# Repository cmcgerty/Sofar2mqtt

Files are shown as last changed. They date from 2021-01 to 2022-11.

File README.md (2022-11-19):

# Sofar2mqtt
## A smart home interface for Sofar solar and battery inverters.

Supported models:  

ME3000SP - Full support  
HYD-xx00-ES - Full support

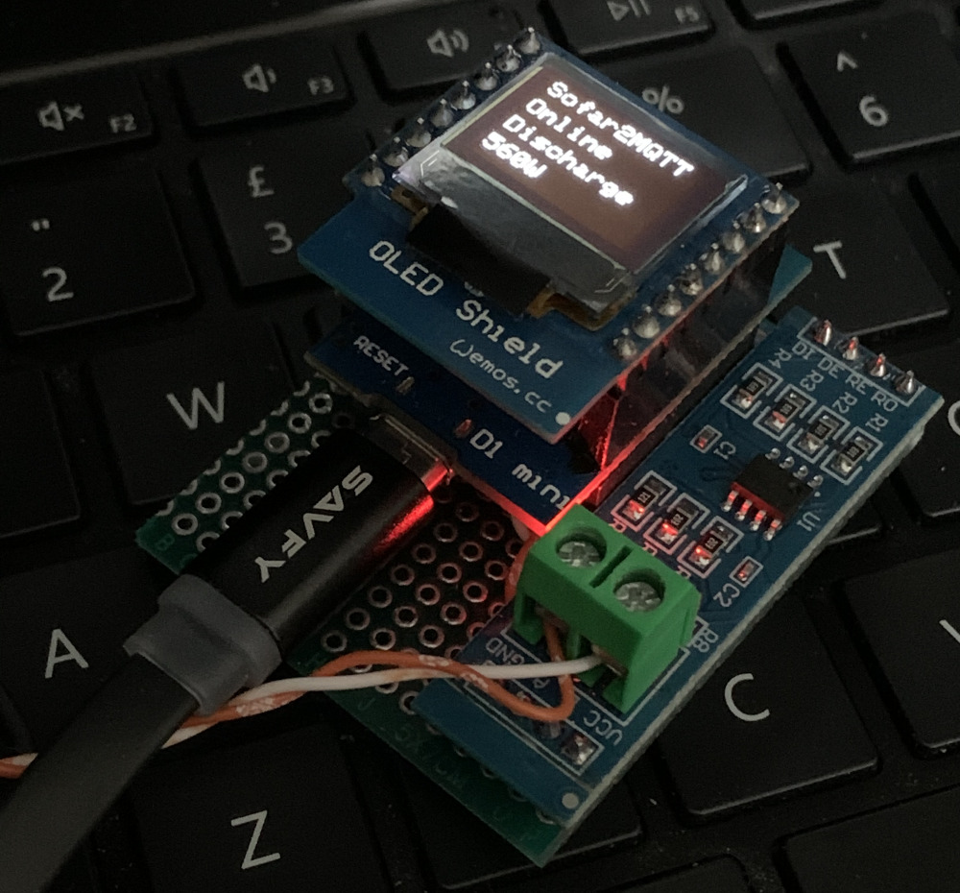
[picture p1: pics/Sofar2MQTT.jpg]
Sofar2MQTT


Sofar2mqtt is a remote control interface for Sofar solar and battery inverters.
It allows remote control of the inverter and reports the invertor status, power usage, battery state etc for integration with smart home systems such as [Home Assistant](https://www.home-assistant.io/) and [Node-Red](https://nodered.org/).  
For read only mode, it will send status messages without the inverter needing to be in passive mode.  
It's designed to run on an ESP8266 microcontroller with a TTL to RS485 module such as MAX485 or MAX3485.  
Designed to work with TTL modules with or without the DR and RE flow control pins. If your TTL module does not have these pins then just ignore the wire from D5. 

Subscribe your MQTT client to:

Sofar2mqtt/state

Which provides:

running_state  
grid_voltage  
grid_current  
grid_freq  
systemIO_power (AC side of inverter)  
battery_power  (DC side of inverter)  
battery_voltage  
battery_current  
batterySOC  
battery_temp  
battery_cycles  
grid_power  
consumption  
solarPV  
today_generation  
today_exported  
today_purchase  
today_consumption  
inverter_temp  
inverterHS_temp  
solarPVAmps  

With the inverter in Passive Mode, send MQTT messages to:

Sofar2mqtt/set/standby   - send value "true"  
Sofar2mqtt/set/auto   - send value "true" or "battery_save"  
Sofar2mqtt/set/charge   - send values in the range 0-3000 (watts)  
Sofar2mqtt/set/discharge   - send values in the range 0-3000 (watts) 

battery_save is a hybrid auto mode that will charge from excess solar but not discharge.

(c)Colin McGerty 2021 colin@mcgerty.co.uk
Major version 2.0 rewrite by Adam Hill sidepipeukatgmaildotcom
Thanks to Rich Platts for hybrid model code and testing.  
calcCRC by angelo.compagnucci@gmail.com and jpmzometa@gmail.com

# How To Build

Parts List:
1. ESP8266 Microcontroller
2. MAX485 or MAX3485 TTL to RS485 board*
3. Wemos 64x48 OLED Screen (optional)
4. A small project board
5. A few wires and a little solder

*The MAX3485 (which is red, not blue like the MAX485 shown here) is preferred as it is much more stable because it uses 3.3v logic, just like the ESP8366. The MAX485 uses 5v logic but is somewhat tolerant of 3.3v and is generally cheaper and more widely available. I use a MAX485 but many people have reported problems with this and if you can find a MAX3485 then you should use that. MAX3485 boards do not have DR and RE flow control pins, so just skip the wire from pin D5 in the wiring diagram below.

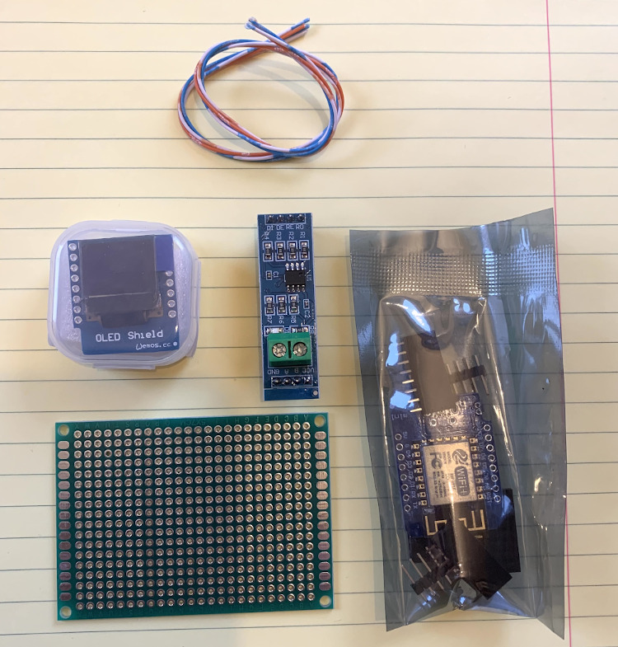
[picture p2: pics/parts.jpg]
Parts


Cut the project board to a convenient size.

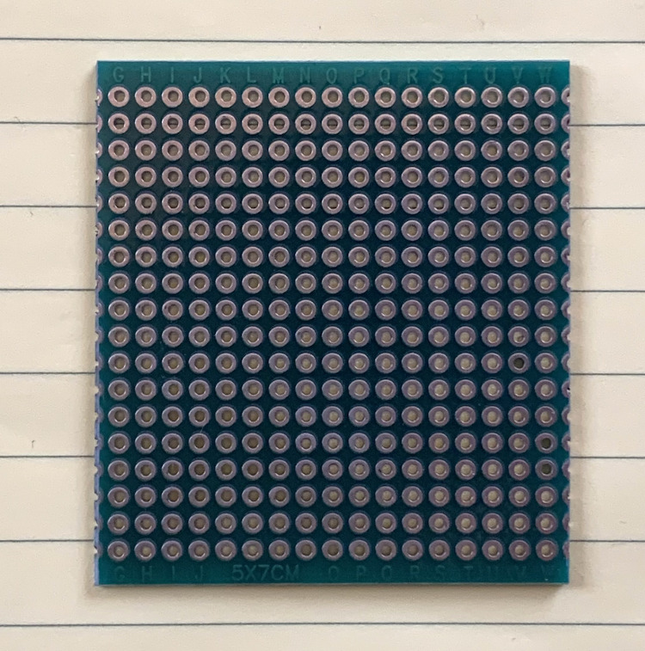
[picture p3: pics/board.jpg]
Board


Wire the components according to this circuit diagram.

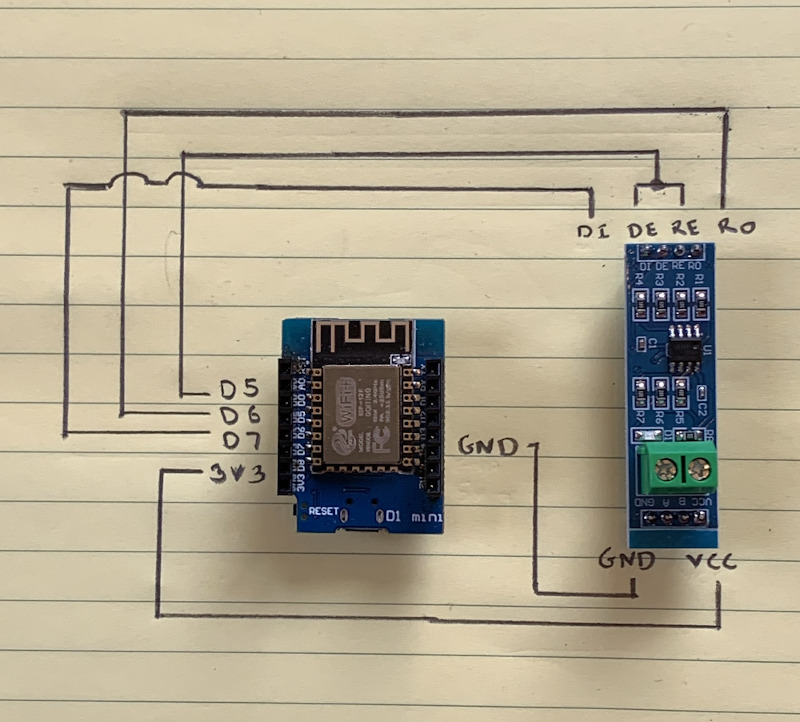
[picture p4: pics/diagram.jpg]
Wiring Diagram


I tend to keep the wires on top of the board, poke them through and solder underneath. Your approach may be better and your soldering will almost certainly be better than mine!

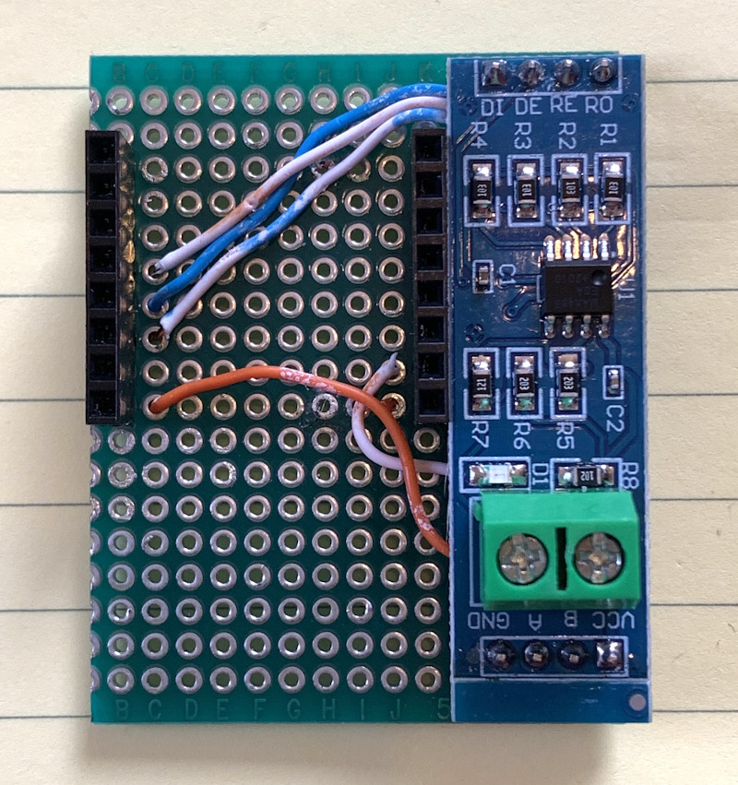
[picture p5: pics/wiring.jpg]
Wiring


Make sure you connect the DR and RE pins together. The red arrow below shows where a single wire from D5 connects to both DR and RE. (If you are using a TTL board without the DR and RE pins, ignore this step.)

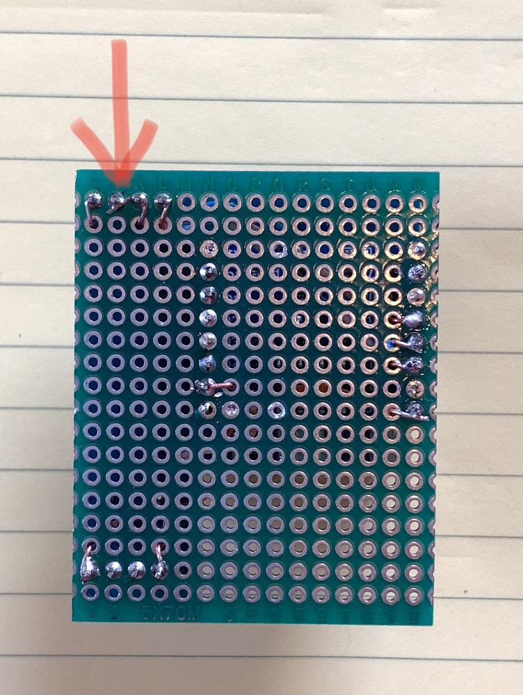
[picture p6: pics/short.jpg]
Short these pins


Use long pinned mounts on your ESP8266 if you are stacking the optional OLED on top. Trim the legs so they fit comfortably into the sockets on the circuit board below.  
I don't recommend soldering the ESP8266 permanently to your circuit board.   

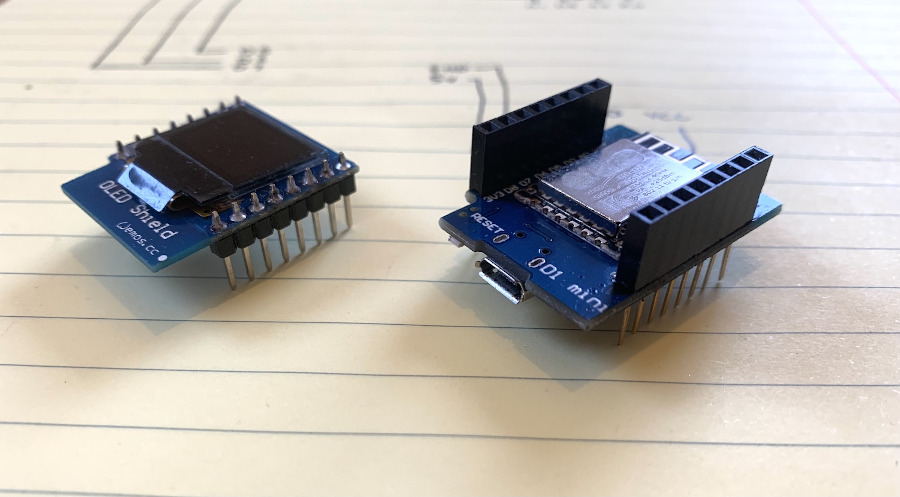
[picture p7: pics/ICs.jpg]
Chips


Here's how it looks when completed.

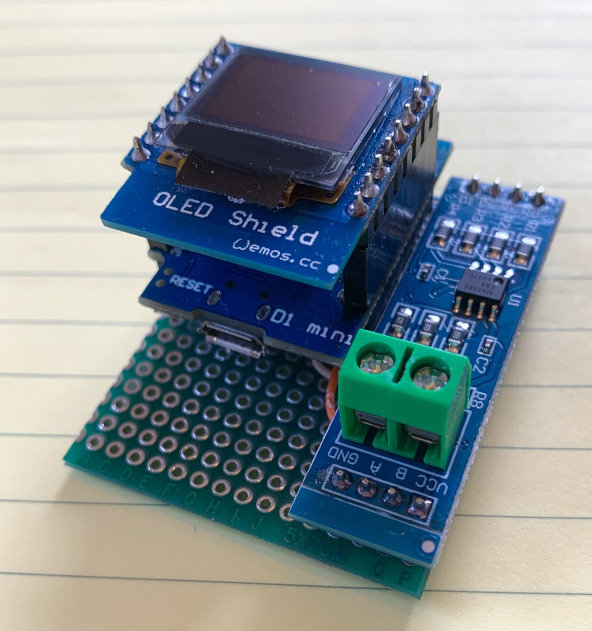
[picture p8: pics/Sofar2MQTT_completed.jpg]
Finished


# Flashing

Edit the file Sofar2mqtt.ino and remove the // at the start of the second OR third line as appropriate for your inverter model (ME3000SP or a Hybrid HYD model).

Add your wifi network name and password and your mqtt server details in the section below. If you need more than one Sofar2mqtt on your network, make sure you give them unique device names.  

You'll need the libraries for the ESP8266. Follow [this guide](https://randomnerdtutorials.com/how-to-install-esp8266-board-arduino-ide/) if you haven't completed that step before.

Add a few more libraries using the Manage Libraries menu:
1. PubSubClient
2. Adafruit GFX
3. Adafruit SSD1306 Wemos Mini OLED

(Even if you are not using the OLED screen, you should install the Adafruit libraries or it will not compile.)

...and upload.

Run it on the desktop, not connected to your invertor, to test that wifi and mqtt are connected and see some messages in the serial monitor.
The OLED screen should show "Online" to indicate a connection to WiFi and MQTT. It will alternate between "RS485 Error" and "CRC-FAULT" to indicate that the inverter is not connected.

# Connect to Inverter

Connect the Sofar2mqtt unit to a 5v micro USB power supply.
Now connect wires A and B to the two wire RS485 input of your inverter, which is marked as 485s on the image of the ME3000SP below.

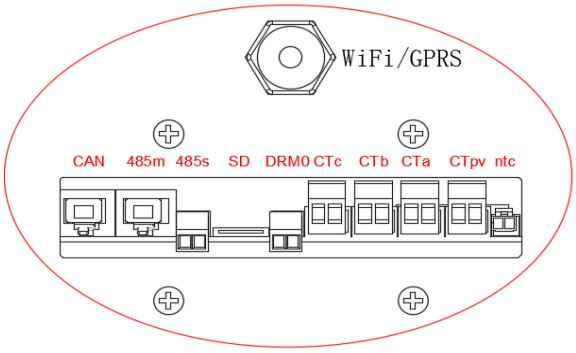
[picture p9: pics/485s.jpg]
ME3000SP Data Connections


# Troubleshooting

Nothing on the OLED screen? Make sure you solder all the pins on the OLED and ESP8266, not just those with wires attached.  
No communication with the inverter? Make sure the slave IDs match. Sofar2mqtt assumes slave ID 1 by default. You can change this around line 93 or in the inverter user interface. But they must be the same.   

Here's what the various things on the OLED screen tell you:

Line 1 is the device name, nothing else.  
Line 2 will display "Connecting" during start up and lines 3 and 4 will show WIFI and MQTT getting connected.  
Line 2 also has a dot that slowly flashes, once every few seconds. This is when a heartbeat message is being sent to the inverter.  
If a message is read from the inverter that fails the CRC checksum, line 3 will display "CRC-FAULT". This could be caused by a loose or bad RS485 wire or by unsupported features. A few of these is normal, a lot could indicate a problem.  
If no response is received to a heartbeat message, lines 3 and 4 show "RS485 ERROR". This could be caused by disconnected or reversed RS485 wires.  
During start-up, line 4 shows the Sofar2mqtt software version. Check that you have the latest version at https://github.com/cmcgerty/Sofar2MQTT  
In normal operation, line 2 shows "Online" which indicates that both WIFI and MQTT are still connected.  
In normal operation, line 3 shows the inverter run state, Standby, Charging, Discharging etc.  
In normal operation, line 4 shows the power in Watts in or out of the batteries when charging or discharging.

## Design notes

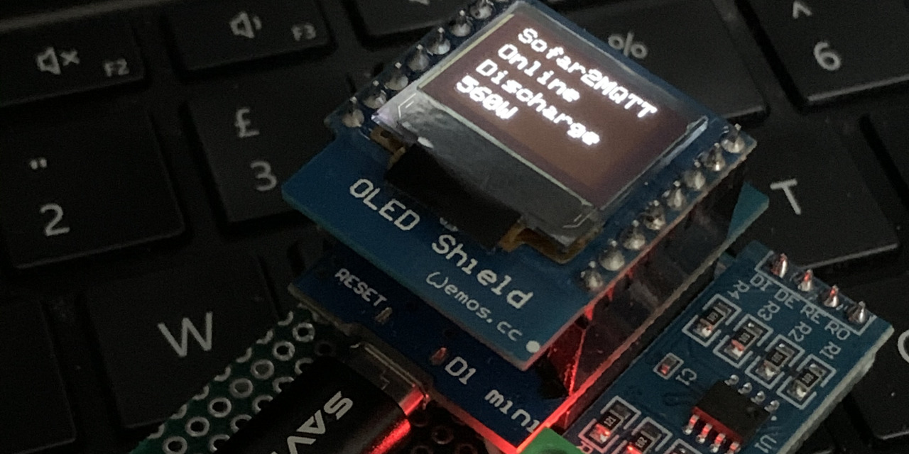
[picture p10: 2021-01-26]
pics/preview.jpg

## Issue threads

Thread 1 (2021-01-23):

Rs485 to ttl with auto flow control

cliffdude, 2021-01-23:
Hi,

Would this code work on an auto flow rs485 to ttl module the one that does not have RE and DE, only rx, tx and vcc and gnd? If not could it be modified to work?
I want to try it on a HYD-4000-ES model but I only have the auto rs485-ttl converter on hand.

cmcgerty, 2021-01-23:
Hi,

Yes, it is tested on this one...
https://www.amazon.co.uk/gp/product/B08HQMDKGR/ref=ppx_yo_dt_b_asin_title_o09_s00?ie=UTF8&psc=1

I've not tested the modbus instructions on anything but the ME3000SP but the Sofar modbus documentation is not model specific. Certainly the Charge and Discharge modes will not exceed 3000W at the moment, but you can change lines 410 and 427 to allow for more.

If you start by testing the read only functions and don't go into Passive Mode, you can see if the output looks sensible.

Let me know how it goes.

cliffdude, 2021-01-24:
UPDATE:
So I built the module with a D1 mini and used the auto flow converter...  and it works!! Awesome work my friend you rock 🥇
In case anyone is madly googling a solution for Sofar Inverter to MQTT I can confirm this is working on the HYD 3-6000 ES models. I have not tested the battery mode yet but I am getting all values via wifi on my MQTT server. Now to build my home assistant dashbord.
RS485 to TTL used was:
https://ae01.alicdn.com/kf/H5299716877f943ae80442061597977df9.jpg
Just to clarify for others, auto flow on uses RS, TX and GND so for this project wemos pin D6 to RX and D7 to TX GND and 5V are joined on Wemos and converter module.
Thank you @cmcgerty 👍

cmcgerty, 2021-01-24:
It’s great to hear that it can read the data for the HYD models. Thanks for the update. I’ll add to the Readme. Let me know how it goes with controlling the charge mode.

I built the first prototype with an auto flow type TTL board so I was knew it had some flexibility there. Glad it works with the one you have.

megamarco833, 2022-12-28:
> UPDATE: So I built the module with a D1 mini and used the auto flow converter... and it works!! Awesome work my friend you rock 🥇 In case anyone is madly googling a solution for Sofar Inverter to MQTT I can confirm this is working on the HYD 3-6000 ES models. I have not tested the battery mode yet but I am getting all values via wifi on my MQTT server. Now to build my home assistant dashbord. RS485 to TTL used was: https://ae01.alicdn.com/kf/H5299716877f943ae80442061597977df9.jpg Just to clarify for others, auto flow on uses RS, TX and GND so for this project wemos pin D6 to RX and D7 to TX GND and 5V are joined on Wemos and converter module. Thank you @cmcgerty 👍

hello i have the same TTL converter but i see some issue:
https://github.com/cmcgerty/Sofar2mqtt/issues/51#issue-1513037724

maybe can you explain how you connect A+ and B- to your inverter?
you used also the GND (beside the B-) ?
thanks

Closed 2021-01-24.

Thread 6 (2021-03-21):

Errors in compile and empty mqtt message

cliffdude, 2021-03-21:
So I have a working module with the old version as you know, I have now built a new one to test the new version that sends all data in the same mqtt message in JSON. Sounds like a good idea to reduce the number of errors and to have all variables update at the same time in HA. Problem is I cannot get any data and I was wondering if the errors in the compile of the code could have caused the problem.
This is what I get in the arduino compiler, however mqtt connects and I get some flashing on the RS485. The inverter also keeps the RS485 logo active on the display however as I said the messages are empty just () on topic "deviceid"/state.
This is the HYBRID.ino
`
/Users/cliff/Downloads/Sofar2mqtt-main/HYBRID/HYBRID.ino: In function 'void mqttCallback(String, byte*, unsigned int)':
/Users/cliff/Downloads/Sofar2mqtt-main/HYBRID/HYBRID.ino:407:22: warning: comparison between signed and unsigned integer expressions [-Wsign-compare]
  for (int i = 0; i < length; i++) {
                      ^
/Users/cliff/Downloads/Sofar2mqtt-main/HYBRID/HYBRID.ino: In function 'modbusResponce listen()':
/Users/cliff/Downloads/Sofar2mqtt-main/HYBRID/HYBRID.ino:671:20: warning: deprecated conversion from string constant to 'char*' [-Wwrite-strings]
   ret.errorMessage = "Valid data frame";
                    ^
/Users/cliff/Downloads/Sofar2mqtt-main/HYBRID/HYBRID.ino:676:20: warning: deprecated conversion from string constant to 'char*' [-Wwrite-strings]
   ret.errorMessage = "Error: invalid data frame";
                    ^
/Users/cliff/Downloads/Sofar2mqtt-main/HYBRID/HYBRID.ino:602:10: warning: variable 'inFunctionCode' set but not used [-Wunused-but-set-variable]
  uint8_t inFunctionCode;
          ^
/Users/cliff/Downloads/Sofar2mqtt-main/HYBRID/HYBRID.ino: In function 'unsigned int batteryWatts()':
/Users/cliff/Downloads/Sofar2mqtt-main/HYBRID/HYBRID.ino:815:1: warning: control reaches end of non-void function [-Wreturn-type]
 }
 ^
`
Keep up the great work!

cmcgerty, 2021-03-22:
Hi.

Those compiler warning are not an issue and the fact that it is connected shows it obviously compiled and installed ok. I would be inclined to check the wiring on your new ttl converter. Better yet, install the update to the existing, known good unit. You can always go back to the previous code if you prefer.

Closed 2021-04-04.

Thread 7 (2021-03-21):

battery_save doesnt stop discharging in auto mode

graememk, 2021-03-21:
Looking at the code, setting battery_save active does not trigger the inverter to change modes.

Possible solution, when battery_save is set active, Put the inverter into standby, then the battery_save routine can take over.

cmcgerty, 2021-03-21:
Hi,

The subroutine batterySave() runs on a timer, once every three seconds. It checks the BATTERYSAVE flag and if true will switch between auto or standby depending if there is excess solar exergy. If energy is flowing to the grid, it switches to auto mode in order to allow the battery to charge, if energy is being imported from the grid then there is no excess solar and the inverter switches to standby. So line 451 only needs to set BATTERYSAVE true, the rest is handed by the already running timer.

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

graememk, 2021-03-21:
Ah I understand,

What if the inverter is already in auto, Discharging, Nothing is being imported from grid, battery is covering the current usage.

Then the off peak time happens, and I want to switch it to battery_save  , sending the battery_save command doesn't stop the inverter from discharging.

But if I send the standby command first and then the battery save, the standby stops the discharge and then the battery save does its business.

graememk, 2021-03-22:
Just after I finished typing that, I had the ME3000 discharging to see the behaviour, and my EV charge kicked in, and that brought the Discharge to a stop. As you described.

graememk, 2021-03-22:
There is still an edge case here, as it's monitoring the grid power,

My scenario was that the inverter was keeping the grid power at 0, from batteries not solar. Only when a high load kicked (say EV, kettle etc) in that it exceeded the output of the me3000.

That's why I suggested initially setting it to standby to get the grid power value not 0. Then the battery save routine can take over and change between standby and auto as needed.

Monitoring the battery discharge could be an option too.

Needless to say I do love the project, have built 3 of them so far for myself and a few friends.

Closed 2021-03-22.

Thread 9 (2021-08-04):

MQTT Rarely Updates

Sku1ly, 2021-08-04:
Hi,

Thanks for making this, I have everything set up and working but I get updates via MQTT maybe every ten minutes and usually only six times. Reboot the nodemcu sometimes brings it back, sometimes doesn't.

Serial monitor shows constant MQTT reconnects and I can see the same in the MQTT server logs.

How often is it supposed to update and have you seen similar behaviour before?

Sku1ly, 2021-08-04:
I think I may have solved this. I think I chose the wrong nodemcu version 1.0 vs 0.9 which caused frequent WiFi drop outs.

Seems to be stable now so will close.

Sku1ly, 2021-08-05:
It wasn't this :(
I've tried two nodemcus and a wemos d1 mini and seeing the same behaviour.

Pinging I see constant drops and errors in serial monitor. It worked for most of today then broke.

Any thoughts?

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

zambujal, 2021-09-30:
Don't know... but it's weird... could be some wire, sometimes things like this happens to me... I redo everything... and then it's working. ;)

cmcgerty, 2021-09-30:
Out of interest, did you also change the ESP8266? There is some question mark in my mind as to whether some are more tolerant of 3.3v logic than others. That said, I normally just use the cheapest ones I can find and don’t have an issue.

On 30 Sep 2021, at 14:32, zambujal ***@***.***> wrote:

Don't know... but it's weird... could be some wire, sometimes things like this happens to me... I redo everything... and then it's working. ;)

—
You are receiving this because you are subscribed to this thread.
Reply to this email directly, view it on GitHub<https://github.com/cmcgerty/Sofar2mqtt/issues/9#issuecomment-931326487>, or unsubscribe<https://github.com/notifications/unsubscribe-auth/ADFHULLX4TAAUMVWKOVS5VTUERRGXANCNFSM5BRROQIA>.
Triage notifications on the go with GitHub Mobile for iOS<https://apps.apple.com/app/apple-store/id1477376905?ct=notification-email&mt=8&pt=524675> or Android<https://play.google.com/store/apps/details?id=com.github.android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>.

zambujal, 2021-10-01:
I used the lol nonemcu cheap 8266 it worked well for me.

________________________________
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

cmcgerty, 2022-04-24:
Hi @zambujal .

Sofar2mqtt V2.0 beta1 has been published today, which is a major write and should bring much greater stability. See if that is better for you.

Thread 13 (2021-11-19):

Json from ESP local server

jezikk82, 2021-11-19:
Hi, would it be possible to present data in json format on local (on ESP) Web server?
I want to integrate it with smart home solution based on plc.

I don't have mqtt server and gateway for my plc so it would be much easier to work with json or any other format with i can get by http request from.

cliffdude, 2021-11-21:
Check out my git SofarCtrl it is a modified copy of Colin's code with a webserver and OTA support.
All original code is there but I have comented out what I did not need such as OLED support.
https://github.com/cliffdude/SofarCtrl/blob/master/HYBRID-WEB_OTA.ino

schritta, 2021-11-30:
@cliffdude
When using the Hybrid-web_OTA , do we still need the mqtt server?
I only need the readings on the local web(esp) and then do a http request from node-red.
Is it then correct not using the mqtt stuff in you code?

jezikk82, 2021-11-30:
Yes, you can not use mqtt. I just commented it out and rest "works".

cliffdude, 2021-11-30:
Yes, you are correct, I use personally mqtt but you do not need to! Check in the code and you will understand what to do.

schritta, 2021-11-30:
Thank you for the quick response.  I have ordered the parts as soon as the arrive I will start this project.
And keep you posted. I aim looking into the code to see what exactly to comment out.

schritta, 2021-11-30:
@jezikk82
Where did you make the connection for the RS485 in your HYBRID, because the pics show only the ME3000SP.
Is there also a 485s connector? I have got the HYB 6000-ES.

jezikk82, 2021-11-30:
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

First from the left is modbus for battery, second (green plug) is for slave devices and you connect max485 with ESP there.

schritta, 2021-11-30:
@jezikk82  Thank you very much i'll check this also with my device.

schritta, 2021-12-04:
Ok , received the espc and setup the hardware on temporary project board.
It works for 99%. Where did you got the register information? Because I don't get "Solarpv2", all other readings are received . So I thought there is a minor issue with the reading of that specific register. I do not know how to debug this.

schritta, 2021-12-04:
my uploaded code in esp
[Hybrid-web_OTA.txt](https://github.com/cmcgerty/Sofar2mqtt/files/7654007/Hybrid-web_OTA.txt)

cliffdude, 2021-12-04:
I think this should be what you need. If you can take the time to debug it
that would be great as I sometime get strange values that I need to filter
out via Home Assistant in order to not mess up my graphs and energy
calculations.

https://docplayer.net/200949628-Sofarsolar-modbus-rtu-communication-protocol.html

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

schritta, 2021-12-04:
thanks I'll try to debug it, but I aim not a specialist.

jezikk82, 2021-12-04:
here you have newer version of modbus for hybrid inverters.
[SofarHYD ES ME3000SP Modbus protocol.pdf](https://github.com/cmcgerty/Sofar2mqtt/files/7654366/SofarHYD.ES.ME3000SP.Modbus.protocol.pdf)

What inverter and datalogger firmware  you have ?
I have v302 and LSW3_15_FFFF_1.0.78 and in my case I cant get any data neither by ModBus RTU or TCP :(

cliffdude, 2021-12-04:
I have the LSW3_14_FFFF_1.0.00 and a HYD-4000-ES with Pylontech Li-on
batteries.
The Wifi logger has nothing to do with this ESP program as it gets data via
the RS485 port on the inverter itself.
You should see an rs485 logo on the inverter screen at the top left if you
have correctly connected the adapter. If you adapter has Leds they should
also flash both tx and rx.
Try swapping the rs485 + and - wires on the inverter.
I did try to connect to the inverter with my pc and an adapter but that did
not work!!!

Good luck

A sábado, 4/12/2021, 17:55, jezikk ***@***.***> escreveu:

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

schritta, 2021-12-04:
I have  SW version 2.90 HW version 1.00 HYB-5000-ES, and yes i got the rs485 symbol in the left upper corner .
@jezikk82 try indeed to swap the + and - rs485 wires.

jezikk82, 2021-12-04:
I see the rs485 logo but the when I try to get data from inverter I got crc error on all 0x03 function code and all registry.
I can take info from 0x04 function and 0x2000 registry = the are serial no, firmware ver etc.

richplatts, 2021-12-04:
The registry is slightly different for HYD
I need to get my windows laptop out to send you my version

Richard Platts  -  07863 249063

On 4 Dec 2021, at 19:54, schritta ***@***.***> wrote:

I have SW version 2.90 HW version 1.00 HYB-5000-ES, and yes i got the rs485 symbol in the left upper corner .
@jezikk82<https://emea01.safelinks.protection.outlook.com/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> try indeed to swap the + and - rs485 wires.

—
You are receiving this because you are subscribed to this thread.
Reply to this email directly, view it on GitHub<https://emea01.safelinks.protection.outlook.com/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>, or unsubscribe<https://emea01.safelinks.protection.outlook.com/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>.
Triage notifications on the go with GitHub Mobile for iOS<https://emea01.safelinks.protection.outlook.com/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> or Android<https://emea01.safelinks.protection.outlook.com/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>.

jezikk82, 2021-12-17:
any update ?

schritta, 2021-12-17:
I have received the mod-bus RTU protocol from sofar 5 days ago, but the Solar PV2 has the same modbus address so i did a calculated solarPv2 value in node red "SolarPV - SolarPV1 = SolarPV2" so now I've got all the data needed to build my node red flows. The most important addresses are listed on page 15 Panel string information see pdf.
Now everything works as planned for me. Thank you to remind me for updating.
[SofarHYD ES Modbus protocol.pdf](https://github.com/cmcgerty/Sofar2mqtt/files/7738102/SofarHYD.ES.Modbus.protocol.pdf)

cmcgerty, 2022-04-24:
Hi All.

Sofar2mqtt V2.0 beta1 has been published today, which is a major write and should bring much greater stability. Any testing would be greatly appreciated. I'm especially keen to get feedback from owners of hybrid inverter models as we have now combined it into a single file. Just uncomment your model at the top of the file.

@cliffdude I still really like your fork that delivers the json output directly. For a Node-Red user like me I could skip the mqtt server entirely. Sorry if it's too much work to merge them. But it might be something we can collaborate on.

cliffdude, 2022-04-24:
I will try your  V2 as I gave stability issues with some of the returned
values Most of the it's fine but I get the odd values that have to be
filtered out. It could be my hardware... If it works better I will try to
add the webserver component and Json output to it.
I just customized your original for my needs.

A domingo, 24/04/2022, 12:27, cmcg ***@***.***> escreveu:

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

cliffdude, 2022-04-24:
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

Would be happy to merge but I removed the LCD that I did not need and we should merge for V2.

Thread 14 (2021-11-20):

No data on Sofar Hyd-3000-es

jezikk82, 2021-11-20:
Hi,

I try to get it working on Sofar hybrid inverter. I checked the addresses and they are correct for my inverter, but unfortunately all the time i get the following error in console and no data are returned:
Send heartbeat
Error: invalid data frame

In function updateRunstate(); when I  print
Serial.println(responce.data[0]); => 218
Serial.println(responce.data[1]); => 255

Can you help me ?

jamesworts, 2022-01-21:
I also have this issue, any solutions?

jezikk82, 2022-01-21:
Unfortunately no, I tested 4 different firmwares (now I'm at v302) and on all the same problem.

Sofar is blind on that problem, I found couple more people with the same issue. Try to send them mails on different addresses, maybe they will react when more people will highlight it.

cliffdude, 2022-01-21:
Sorry it's not very helpful but I have v285 on the HYD-4000-ES and it works
fine. Sounds like Sofar may have changed something in the v3 firmwares.

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

jezikk82, 2022-01-21:
I started with 235 from facrory, later tested 270, 280, 300, 302. On none of this firmwares it worked.

1. Can you share your firmware version?
2. What version of data logger (lsw) you have?
3. Do you think firmware from hyd400 will work on hyd3000?

jamesworts, 2022-01-22:
mine is v310 and not working.

cliffdude, 2022-01-22:
Hi,

The wifi adapter has nothing to do with Colin's device / code, as this uses
the RS485 port that is for talking to a paired inverter in a Master / Slave
configuration.
The HYD-xxxx-ES series are identical (as far as I know), I have friend with
a HYD-5000-ES and it is the same, he is running v280, I would even go as
far as to think that the output limitation is in the software?!?
Are you sure that your TTL adapter is ok, I built 3 of them and only one
works? Aliexpress... what can I say. It is far more likely to be an issue
with your device / build than a firmware issue with the inverter, also
check your power source for the esp and ttl - rs485.

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

cmcgerty, 2022-04-24:
Hi All.

Sofar2mqtt V2.0 beta1 has been published today, which is a major write and should bring much greater stability. See if that is better for you. I'm especially keen to get feedback from owners of hybrid inverter models as we have now combined it into a single file. Just uncomment your model at the top of the file.

innerlurken, 2022-04-28:
Hi, I'm using a HYD5000 hybrid inverter and have updated to version 2, it's working much better, seems very stable now, thank you

Question, do you have an updated node red function? The current one does not seem to work for me.

davies8172, 2022-04-28:
> Hi, I'm using a HYD5000 hybrid inverter and have updated to version 2, it's working much better, seems very stable now, thank you
>
> Question, do you have an updated node red function? The current one does not seem to work for me.

If you are looking for up to date Node-Red flows, goto https://www.facebook.com/groups/2477195449252168
You will find the most recent Node-Red flow (for Sofar2MQTT) at https://www.facebook.com/groups/2477195449252168/permalink/2570410946597284

innerlurken, 2022-04-30:
Thank you, the new flow helped loads, the new version is very good, thank you for all your work on this

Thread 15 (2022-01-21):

Continuous disconnections to the MQTT broker

Simoverdex, 2022-01-21:
Hi, I recently made the sofar2mqt project. It works great except that sporadically the device disconnects to the mosquet broker, and I am forced to remove and restore power to the device to reconnect the broker. I have increased the Keepalive value in the mosquet configuration, but the situation does not change. Does anyone have any suggestions about it?

I Have Home Assistant OS 2021.12.10 on Raspberry PI 4

This is the Mosquitto Log
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

cmcgerty, 2022-04-24:
Hi @Simoverdex .

Sofar2mqtt V2.0 beta1 has been published today, which is a major write and should bring much greater stability. See if that is better for you.

Closed 2022-04-30.

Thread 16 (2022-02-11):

crash in discharge mode

Argenlos, 2022-02-11:
Hello, and thank you for this useful tool.
I have modified your code a bit to display in the console the results, because I don't have an OLED, but I have my data displayed in the console..everything is fine.
But, I have a problem.
When the ME3000SP inverter goes into "discharge" mode by itself, at the end of the day, you hear the inverter switches, to switch to discharge mode, the esp8266 crashes and restarts all the time.

In charge mode and in standby no worries.

I really don't know where to start looking for the problem, because this little assembly works...but not in discharge.

The firmware is V280 on the inverter
I use a nodemcu rather than a D1 mini.
I tested with another power supply just in case.

[error.txt](https://github.com/cmcgerty/Sofar2mqtt/files/8051275/error.txt)
Good evening.

cmcgerty, 2022-02-11:
Sorry to say that I have seen this problem before with devices other than esp8266. Even cheap esp8266s can have this problem. I think the issue is how tolerant it is of the MAX485 board, which would prefer a 5v input. If you use a MAX3485 it may be more stable. And the wiring is actually simpler as MAX3485 doesn't need the DE/RE wire as it is auto-switching. The only reason I don't recommend them to everyone is they are much less common.

Thanks,
Colin
________________________________
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

Argenlos, 2022-02-12:
Hello, thank you for your quick feedback.
I have just tested in 5V on the MAX485 with another ESP8266 and another MAX485.
This morning, when charging the battery, the frames are no longer recognized when switching from standby mode to charging.
I will follow your advice and think about switching to a MAX3485 and another eps8266 of better quality.
I will keep you informed of progress.
Have a good day

Argenlos, 2022-02-17:
Hello,

I received 2 new D1 mini. One clone and one original (Lolin V3.1.0) that I test with a MAX485...and well it's worse, no return even in standby mode on the inverter, the D1 connects the wifi, the mqqt, then crashes with hexa code pages. It reboots again and again.
I put an external power supply of 5V (5A) for the D1 and another for the MAX485...you never know, but it's not that.

I redid the board completely...maybe...but it's not that...(no choice because I had to redo the board for a D1 mini)

I just took the INO file, added the libraries (in Arduino IDE), added the Wifi and Mqtt parameters, compiled without worries (with the right type of board)...and it's not the first assembly with esp that I do.

Of course, I tested with a second, a third MAX485 (component tolerance, etc...), still not that.

With an MCU node at least in standby mode it gives consistent values on frequency, voltage ... (with a very dirty Serial.print in the code), with a D1 mini clone or an original D1 mini, and although frame errors.

Now let's find a MAX3485...:)

Bye

Argenlos, 2022-02-20:
Hello,

The MAX3485 adapter saved me :)
I think you should recommend the MAX3485 before trying the MX385 which doesn't do the job, or with a lot of luck.

Thanks for the advice.

Sincerely,
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

Closed 2022-02-20.

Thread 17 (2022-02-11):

readme should say subscribe Sofar2mqtt/state - capital S

rustle118, 2022-02-11:

rustle118, 2022-02-11:
Sofar2mqtt/state currently readme has lower case s for sofar

cmcgerty, 2022-02-11:
Quite so. My bad. The mqtt message root is actually whatever you call the device in the line deviceName = "Sofar2mqtt";

Thanks,
Colin
________________________________
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

cmcgerty, 2022-04-24:
V2.0 beta1 has been published today, which is a major write and bring much greater stability. See if that is better for you.

Closed 2022-04-24.

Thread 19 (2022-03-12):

control reaches end of non-void function [-Werror=return-type]

Tinbum1, 2022-03-12:
I'm having trouble compiling for the ME3000 and getting the above message and the last line of this part of the sketch highlighted;
`
unsigned int batteryWatts()
{
  if (INVERTER_RUNNINGSTATE == charging || INVERTER_RUNNINGSTATE == discharging)
  {
    modbusResponce responce = sendModbus(getBatteryPower, sizeof(getBatteryPower));
    if (responce.errorLevel == 0)
    {
      unsigned int w = ((responce.data[0] << 8) | responce.data[1]);
      switch (INVERTER_RUNNINGSTATE)
      {
        case charging:
          w = w * 10;
          break;
        case discharging:
          w = (65535 - w) * 10;
          break;
      return w;
      }
    }
    else
    {
      Serial.println(responce.errorMessage);
      updateOLED("NULL", "NULL", "CRC-FAULT", "NULL");
    }
  }
  else
  {
    return 0;
  }
} HERE
`

cmcgerty, 2022-04-24:
Hi @Tinbum1
V2.0 beta1 has been published today, which is a major write and bring much greater stability. See if that is better for you.

Closed 2022-04-30.

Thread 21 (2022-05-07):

Support for HYD 8KTL-3PH

pixellos, 2022-05-07:
Hi, wanted to ask if given inverter is supported.

cmcgerty, 2022-05-07:
Hi,

I would expect this model to be supported. Use version 2.0, uncomment line 3 and comment out line 2.

Please update this thread if you are able to confirm it working on this model.

Thanks

On 7 May 2022, at 17:47, Mateusz Popielarz ***@***.***> wrote:

Hi, wanted to ask if given inverter is supported.

—
Reply to this email directly, view it on GitHub<https://github.com/cmcgerty/Sofar2mqtt/issues/21>, or unsubscribe<https://github.com/notifications/unsubscribe-auth/ADFHULPMF67RQ6ZI6M5PTJTVI2NCNANCNFSM5VKUNOLQ>.
You are receiving this because you are subscribed to this thread.Message ID: ***@***.***>

cliffdude, 2022-05-08:
If you can confirm that the protocol is the same as the other HYD models,
and I don't see why it would not be, then it should work. I have a single
phase HYD model and it works fine.
The only way would be to ask for the protocol details on the forum or
directly from Sofar, the problem is they are not always willing to give out
that information.

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

maxxximatoze, 2022-05-11:
> If you can confirm that the protocol is the same as the other HYD models, and I don't see why it would not be, then it should work. I have a single phase HYD model and it works fine. The only way would be to ask for the protocol details on the forum or directly from Sofar, the problem is they are not always willing to give out that information.
> […](#)
> On Sat, May 7, 2022 at 6:26 PM cmcg ***@***.***> wrote: Hi, I would expect this model to be supported. Use version 2.0, uncomment line 3 and comment out line 2. Please update this thread if you are able to confirm it working on this model. Thanks On 7 May 2022, at 17:47, Mateusz Popielarz ***@***.***> wrote:   Hi, wanted to ask if given inverter is supported. — Reply to this email directly, view it on GitHub< #21>, or unsubscribe< https://github.com/notifications/unsubscribe-auth/ADFHULPMF67RQ6ZI6M5PTJTVI2NCNANCNFSM5VKUNOLQ>. You are receiving this because you are subscribed to this thread.Message ID: ***@***.***> — Reply to this email directly, view it on GitHub <[#21 (comment)](https://github.com/cmcgerty/Sofar2mqtt/issues/21#issuecomment-1120245764)>, or unsubscribe <https://github.com/notifications/unsubscribe-auth/AOGAXEGW3NTWSUTK22DZESLVI2RVLANCNFSM5VKUNOLQ> . You are receiving this because you are subscribed to this thread.Message ID: ***@***.***>

Hello, what model of HYD single phase do you have and how do you make it works with it ? Because I have a HYD6000-EP, and I can't make it works with it for now (:

cmcgerty, 2022-10-25:
Not very promising. Have you tried swapping the two RS485 wires?

tomipaci, 2022-10-25:
Yes, I think it then reports an RS485 error. Do you have any idea? Or does the HYD 15 KTL have a different addressing?

ruben05041991, 2023-01-15:
Anyone who got it working for a HYD xx KTL 3PH inverter?

LotharF, 2023-02-07:
I'm also use a HYD 8KTL 3PH and try to use the latest Sofar2mqtt Version 2.1. But it will not work.
I connect the A and B cable with Pin 1+4 of the "Multiconnector" of my HYD. The only result is "Heartbeat -2".

pixellos, 2023-02-07:
Maybe U want to try a project i hacked some time ago - https://github.com/pixellos/codereinvented.automation.py - its communicating thru wifi logger, so no custom board etc

Mocky158, 2023-03-14:
I would also like hyd KTL support I have version 20
I have an excel document with the given registers for the HYD KTL version if that helps.
[SOFAR-G3 External Modbus Protocol-EN-V1.10 (20220622).xlsx](https://github.com/cmcgerty/Sofar2mqtt/files/10964325/SOFAR-G3.External.Modbus.Protocol-EN-V1.10.20220622.xlsx)

hruskaexe, 2023-09-13:
Hi, please will this issue be resolved, is it being worked on? Thanks

Stronzo-sky, 2023-11-02:
hi, i have hyd-5k20ktl-3ph - any chance theese invertors will be supported with Sofar2mqtt?

wichr, 2024-05-14:
This version suport Sofar HYD KTL. https://github.com/IgorYbema/Sofar2mqtt

LotharF, 2024-05-15:
Shure? I have installed the software and get only mqtt values with "0" via mqtt. I use the "HYBRID.ino". Maybe I have to change something more here if I have a SofarSolar HYD 8KTL 3PH ?

LotharF, 2024-07-19:
I have some trouble with the version from IgorYbema. It was running for a while and then no data. After I change the rs485 board all is running fine again. And nor the same. Tee re485 board seems to be damaged again. Is this normal or is the rs485 board from Amazon to cheap to run for long time?

cliffdude, 2024-07-20:
I had the same issue, I had to restart the ESP periodically. In the end it
was the power supply that I was using that was also connected to my
pylontech battery.

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

peterdedecker83, 2025-02-20:
On my ME3000SP I have the same problem, already tried swapping the two wires. What else could be wrong and how to investigate? Thanks.

21:45:50.724 -> Response too short
21:45:51.304 -> Timeout waiting for RS485 response.
21:45:51.337 -> Response too short
21:45:51.919 -> Timeout waiting for RS485 response.
21:45:51.952 -> Response too short
21:45:52.533 -> Timeout waiting for RS485 response.
21:45:52.564 -> Response too short
21:45:52.693 -> Send heartbeat
21:45:53.309 -> Timeout waiting for RS485 response.
21:45:53.341 -> Response too short
21:45:53.341 -> Bad heartbeat -2
21:45:53.372 -> Get runstate: Timeout waiting for RS485 response.
21:45:54.016 -> Response too short
21:45:54.016 -> Response too short
21:45:54.661 -> Timeout waiting for RS485 response.
21:45:54.694 -> Response too short
21:45:55.274 -> Timeout waiting for RS485 response.
21:45:55.274 -> Response too short
21:45:55.859 -> Timeout waiting for RS485 response.
21:45:55.891 -> Response too short
21:45:56.475 -> Timeout waiting for RS485 response.
21:45:56.508 -> Response too short

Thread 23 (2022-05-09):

Version 2.0b1 response value

double1968, 2022-05-09:
I have upgraded to version 2.0
everything works and the system seems more stable.
I don't understand why I send the commands to my HYD4000 sometimes I receive in the topic "Sofar2mqtt/response/" the value 512 as an answer while the notes report this:

The result code will be 0 for success, 1 means "Invalid Work Mode" (which possibly means
the inverter isn't in passive mode,) and 3 means "Inverter busy." 2 and 4 are data errors
which shouldn't happen unless there's a cable issue or some such.

Many Thanks

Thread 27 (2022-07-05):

How do you power the ESP8266?

jaimelaborda, 2022-07-05:
I have a HYD-4600-ES, and couldn't found a 5V pin to power the microcontroller from the inverter.

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

Any of you with the same problem? How have you solved it?
I would like to try as much as possible not to have to power it externally.

Thank you!

Ernest-burgess, 2022-12-03:
hi do you not have a port for conecting the wifi interface that they use to send data to the cloud
this will have a 5 volt output i would expect on this interface to power the external dongal/ wifi transmitter .
i have also fitted a small 5 volt power suppy in the case with two red mains wires  and two 5 vdc wires these can run up to 1 amp at 5 volts and these seem to work well been running them for over 2 years  it is a ebay item 253302424410  these are in there own case so mains is isolated from your board you need to extend the two red mains wires and include a mains fuse only needs to be small 500ma to 1Amp  then you can conect this to the mains input terminal of the inverter.

headcloudmonkey, 2023-03-17:
I've built a small DB9 male/female passthrough to put between the logger and the inverter. Off of that, I pull 5v from pin 9, and ground from pin 5. These are connected to the 5v/gnd pins on the esp8266. Saves running separate supplies for it,.

cliffdude, 2023-03-17:
Great idea, why didn't I think of that? Duh. I have a bunch of those lying
around from old PC serial port connectors.
Have you been running your solution for some time?  I just wondered how
stable the power was with both esp and wifi dongle.

On Fri, Mar 17, 2023 at 6:05 PM Daniel Gould ***@***.***>
wrote:

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

headcloudmonkey, 2023-03-18:
I've had mine using that for a long time and it seems stable for both the ESP8266 and the logger.

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

OGB1952, 2023-03-21:
Great tip about getting 5V from the DB9.  Presumably that DB9 also has either RS485 or perhaps TTL level RS232, to send data to the Solarman logger.  I'm keen to get rid of the Solarman logger (don't like having my data going to a server in China).  It's occurred to me that it might be possible to make a replacement for the Solarman stick that includes an ESP8266 running Sofar2mqtt.

It would be a very neat solution to have a new dongle that just plugs into the DB9 and only sends data locally to HA.

Anyone happen to know the pinout for that DB9 connector on the ME3000SP (probably the same on some other Sofar inverters)?

I could reverse engineer the Solarman logger, but given the price of the things I'm reluctant to break it open!

headcloudmonkey, 2023-03-25:
Checked the standard pin numbering for DB9 connectors. On this photo, the pin with the square pad is pin 1, pin 5 ground, pin 9 +5vdc, and 2 & 3 data
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

OGB1952, 2023-03-25:
Brilliant!  Many thanks.

A replacement dongle, with an ESP8266 and perhaps a modified version of Sofar2mqtt could  be very neat and tidy.  It'd be a lot easier to just plug a DB9 into the inverter than faff around with dangling wires and a separate 5V power supply.

Pity there isn't more documentation about these inverters.  Make life a lot easier if they just published the interface spec.

headcloudmonkey, 2023-03-25:
I'm suspecting that it is going to be a read-only interface, given that it's intended to be a logger connected to it, and that they provide the RS485 for the more interactive pieces. But with the RS485 port in close proximity there, it wouldn't be too difficult to add wires to the spare DB9 pins to connect to the RS485 port inside the case. Then the unit can do both if needed! Let's see what I can find by snooping the RS232 first and go from there :-)

OGB1952, 2023-03-25:
Could be MODBUS over RS232, perhaps?

Would make sense for the inverter to use MODBUS internally and just have both the RS485 and RS232 connections to the same internal bus.  Could also be Solarman playing fast and loose when they state that the LSW-3 uses RS232.

OGB1952, 2023-03-25:
Just found another data sheet for the Solarman LSW-3 that has more info, although it is a bit confusing:

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

It mentions both RS485 and RS232, so I'm wondering if it's really just a duplicated RS485 port.  That would make some sense, with RS485 being multi-drop.  If we're REALLY lucky then it's really MODBUS over RS485, just like the other RS485 port.  If so, that would allow a direct connection for a Sofar2mqtt dongle, with the DB9 providing both power and data, with no mods.

I'd go out and test this right now, but my ME300SP is outside in a small shed, and it's tipping it down with rain here at the moment!

headcloudmonkey, 2023-03-25:
Hmmm, gave it a go and just CRC errors whichever way round I had the tx/rx

headcloudmonkey, 2023-03-25:
I'm suspecting the logger is just an esp8266 inside anyway, with the native tx/rx on it used to connect

headcloudmonkey, 2023-03-25:
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

I don't use the solarman app these days anyway, so I've disassembled the logger

headcloudmonkey, 2023-03-25:
tx/rx from the DB9 go to a Sipex 3232EE, which is an RS232 driver

https://www.sparkfun.com/datasheets/Components/General/sp3222_3232e.pdf

so we know it's just RS232 there then. I'm still trying to find my RS232 breakout cable...

headcloudmonkey, 2023-03-25:
https://fccid.io/2ACSV-HF-LPT230/User-Manual/Users-Manual-3552381.pdf

This is the module, provides wifi data transfer for serial devices.

OGB1952, 2023-03-25:
Great work!  Looks like the heavy lifting is done by this N76E003 Nuvoton microcontroller, with it's associated SPI flash memory chip:

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

https://www.nuvoton.com/products/microcontrollers/8bit-8051-mcus/low-pin-count-8051-series/n76e003/

The datasheet is here: https://www.nuvoton.com/export/resource-files/DS_N76E003_EN_Rev1.10.pdf

Seems to be a clone of the venerable 8051, so not the most capable device around.  Means it can't be doing much, I think, little more than serving up that very simple local webpage and handling the TCP/IP comms to the Solarman servers.

Knowing that there is TTL level RS232 comms on that port gets us a bit closer to being able to make a variant of Sofar2mqtt that doesn't need an RS485 to RS232 converter.  I believe that the default baud rate for the Solarman LSW-3 is 9600, although the UART in the N76E003 can go up to 115,200.   The Sofar RS485 port runs at 9600 baud, so my best guess is that this RS232 port will be the same.

I may have a go tomorrow (weather permitting) to see if it's running MODBUS over RS232.  I think there is a fair chance it may be.  If so, then we could get really lucky and be able to just connect the software serial port of the ESP8266 to the DB9 Rx/Tx.  I have some DB9's around somewhere, and also have a spare breadboard Sofar2mqtt.  I will try and have a go at hooking something up, and, weather permitting, have a go with it tomorrow.

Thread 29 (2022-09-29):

upgraded to 2.0b1 but still CRC errors

javiermitchell, 2022-09-29:
I have upgraded to 2.0b1 and found it more stable - I think -
However, when I thought everything was sorted I'm getting one of those dreaded "CRC-FAULT"errors
So things are still not completely fixed, by the looks of it.
The annoying thing is there doesn't seem to be quick solution: you just leave it as it is and it will sort itself after it restarts the next day

In any case, I think this is a good effort

double1968, 2022-09-29:
since I have been using this adapter instead of the blue one I have not had any problems for now.
I'm on 2.0b1 too.
Also on github they recommend it

[https://www.amazon.it/gp/product/B096ZXXKCR/ref=ppx_od_dt_b_asin_image_s00?ie=UTF8&psc=1](url)

javiermitchell, 2022-09-29:
what do you mean?
this ONE is BLUE!

double1968, 2022-09-29:
[https://github.com/cmcgerty/Sofar2mqtt](url)

section How To Build

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

javiermitchell, 2022-09-29:
sorry, I misunderstood: you MEANT the blue BOARD, I thought you meant the blue CONNECTOR
so should be the red BOARD
Thanks

frogsuk, 2022-09-30:
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

This is not the MAX3485 Chipped board as quoted in GitHub. It is the MAX13487E board and there is a difference.
Please see attached data sheets.
Always check the main chip in the board for it's number as not always described correctly

https://datasheets.maximintegrated.com/en/ds/MAX13487E-MAX13488E.pdf

https://datasheets.maximintegrated.com/en/ds/MAX3483E-MAX3491E.pdf

Closed 2022-11-19.

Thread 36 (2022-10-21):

Time out waiting response too short

Rockument, 2022-10-21:
MQTT Connected , But RS485 said response too short how it fix thanks.

jamesdcockayne, 2022-10-31:
I had that error when my twisted pair was not connected to the inverter. Check your wiring?

Closed 2022-11-19.

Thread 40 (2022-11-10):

node red flow does not work

Ernest-burgess, 2022-11-10:
hi the node red flow funtion node  does not seem to act on any of the payload values
i have a debug node on what goes in  and one on the output  and they both show the same data it does not seem to be formating the data.
ie the running state  shows as value 4 in the input   and still as value 4 in the output   the globle variable holds the string "Unknown"
so it seems to be droping right through the case statment  .
i have tried the funtion node that was uploaded a few days ago with revision 2 of the code  but this still does the same
does any one have this working ?
regards bill

cmcgerty, 2022-11-10:
Hi Bill,

The function works fine. Sorry if you are struggling to get it working in your system, I know it can be a pain. Could you ask your question in the discussion area?

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

Ernest-burgess, 2022-11-10:
Hi thanks for the prompt reply
That was what I was expecting to see  sorry I am new to this  this is a picture of what I am getting I wonder if it could be something in the set up of node red ? [cid:42225D64-80A4-4570-B874-E72D880D1839]

Regards. Bill

On 10 Nov 2022, at 09:05, cmcg ***@***.***> wrote:

Hi Bill,

The function works fine. Sorry if you are struggling to get it working in your system, I know it can be a pain. Could you ask your question in the discussion area?

[Format]<https://user-images.githubusercontent.com/13269549/201046975-acdda849-5bef-4186-81d8-cb960e3586d9.png>

—
Reply to this email directly, view it on GitHub<https://github.com/cmcgerty/Sofar2mqtt/issues/40#issuecomment-1309974743>, or unsubscribe<https://github.com/notifications/unsubscribe-auth/ALRW66F6C6RJO6JXI6SLDKTWHS3D3ANCNFSM6AAAAAAR4JEQ6U>.
You are receiving this because you authored the thread.Message ID: ***@***.***>

davies8172, 2022-11-10:
Check out this file to get you started. It is the original Sofar2MQTT flow for Node Red which works perfectly. It outputs to MQTT but you can change that to where-ever you like. :)
https://www.facebook.com/groups/2477195449252168/permalink/2570410946597284

Ernest-burgess, 2022-11-10:
Fixed it. Spent all last night on this. And your msg. Just made me think about the output from the Mqtt conection node. Set it to a parsed JSON object. Now works fine

Thanks

Regards. Bill

On 10 Nov 2022, at 09:05, cmcg ***@***.***> wrote:

Hi Bill,

The function works fine. Sorry if you are struggling to get it working in your system, I know it can be a pain. Could you ask your question in the discussion area?

[Format]<https://user-images.githubusercontent.com/13269549/201046975-acdda849-5bef-4186-81d8-cb960e3586d9.png>

—
Reply to this email directly, view it on GitHub<https://github.com/cmcgerty/Sofar2mqtt/issues/40#issuecomment-1309974743>, or unsubscribe<https://github.com/notifications/unsubscribe-auth/ALRW66F6C6RJO6JXI6SLDKTWHS3D3ANCNFSM6AAAAAAR4JEQ6U>.
You are receiving this because you authored the thread.Message ID: ***@***.***>

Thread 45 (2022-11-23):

Support for HYD 3-6K-EP

wardwygaerts, 2022-11-23:
If I'm correct there's only support for the HYD ES inverters, but not for the EP ones. These have other registries.
Are there plans to add this support?

cliffdude, 2023-02-08:
If someone could find the register value map it would certainly be possible. I may need to upgrade my ES inverter to a bigger EP model (better EPS mode and higher batt charge current) so I am interested.

lugio, 2023-02-11:
Hello, still no support planned ?
 thank you

cmcgerty, 2023-02-11:
Not at the moment, no. Sorry @lugio

lugio, 2023-02-11:
Thks for you response
😞

lugio, 2023-02-11:
this project manages to recover the information via rs485, it is possible to based on this one for the adapted to yours?
[https://gitlab.com/rjpearce/sofar2mqtt](url)

cliffdude, 2023-02-11:
@luigii

I am currently upgrading my solar install and may swap my ES inverter with
an EP model with higher power.
If that does happen I will attempt to add support for the EP as I would
like to keep my ESP device to be able to control the inverter.
A long shot but check back here in future, you never know :)

A sábado, 11/02/2023, 16:16, lugio ***@***.***> escreveu:

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

lugio, 2023-02-12:
I'm crossing my fingers then :)
 Is that what you're looking for? :

[esphome_sofarsolar_hydxxxxep_modbus.txt](https://github.com/cmcgerty/Sofar2mqtt/files/10716240/esphome_sofarsolar_hydxxxxep_modbus.txt)

cliffdude, 2023-02-12:
Thatis very useful, esphome is a great platform f9r anyone using home
assistant. I use it for many other sensors as the response time is way
better than mqtt.
Have you tried this out?

A domingo, 12/02/2023, 14:21, lugio ***@***.***> escreveu:

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

lugio, 2023-02-12:
Yes I am currently sending the data to Home Assistant
RS485 > USB > vm linux > mqqt

Thanks to the project:
https://gitlab.com/rjpearce/sofar2mqtt/-/blob/main/README.md

It works fine, but read only.

wardwygaerts, 2023-02-12:
I connected my EP to a RS485 to ETH server (Waveshare), which sends all data via mqtt. Is working fine!

rjpearce, 2023-02-20:
@cmcgerty I can probably change the code to support EP and send you an MR but I don't want to make your code complicated.

How would you feel about pulling out the data (eg. registry addresses) to a separate file per model i.e a JSON file or at least a .h file. For example: https://gitlab.com/rjpearce/sofar2mqtt/-/blob/main/sofar-hyd-ep.json

Splitting the data from the code makes the code easier to maintain and adding support for new models is as easy as adding a file.

I also don't have a way to test but it looks like @lugio is up for that.

lugio, 2023-02-26:
Work base ?
[(https://github.com/cmcgerty/Sofar2mqtt/discussions/57)]

joostvdveen, 2023-03-17:
I am looking for the HYD 3-6K-EP registry addresses to send Charge and Discharge command to the inverter. For me that is the most important functionality i need. anyone?

rjpearce, 2023-03-17:
> I am looking for the HYD 3-6K-EP registry addresses to send Charge and Discharge command to the inverter. For me that is the most important functionality i need. anyone?

https://www.facebook.com/groups/2477195449252168/permalink/3047428435562197
"0x1187" also known as 4487

joostvdveen, 2023-03-18:
> > I am looking for the HYD 3-6K-EP registry addresses to send Charge and Discharge command to the inverter. For me that is the most important functionality i need. anyone?
>
> https://www.facebook.com/groups/2477195449252168/permalink/3047428435562197 "0x1187" also known as 4487

Sorry i don't have Facebook
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

rjpearce, 2023-03-19:
[Remote Control Description for SOFARSOLAR Hybird Inverter HYD (3).pdf](https://github.com/cmcgerty/Sofar2mqtt/files/11010905/Remote.Control.Description.for.SOFARSOLAR.Hybird.Inverter.HYD.3.pdf)

Loudo42, 2023-03-19:
Hi,

For those who want to have the good register and config, you can have a look to my reply here.
[https://github.com/cmcgerty/Sofar2mqtt/discussions/26#discussioncomment-4242730]

I still have to set up the remote control.
I had a look on the python code of the hyp-ep-remote-control.py of Andre Wagner in the facebook group, but I do not understand all the code to write the registers and I do not know how to adapt it in Sofar2mqtt.

I was thinking a easiest way to remote it.
The idea is to change only 1 register to switch between self use mode and time-of-use-mode.
In the inverter, we have to set up 1 rule of time of use mode, with a charge at 0W all the time, so it will correspond to standby mode.
Here is the code to change in Sofar2mqtt:
First for HYP-EP, I think we have to set up
#define SOFAR_FN_AUTO	0x4368

In the void sendData() section:

if(cmd == "standby")
	{
		sendPassiveCmd(SOFAR_SLAVE_ID, SOFAR_FN_AUTO, 1, "standby")
//1 is Time-of-use mode, so set a enabled rule with charge 0W
		Serial.println("standby");
		}
	}
	else if(cmd == "auto")
	{
		sendPassiveCmd(SOFAR_SLAVE_ID, SOFAR_FN_AUTO, 0, "auto")
		Serial.println("auto");
	}

Could you please let me know if it is ok and if I can try it.

Thank you in advance.

rjpearce, 2023-03-19:
Why not use Passive Mode (3) ?
You can then specify the charge/discharge rate using register 0x1187.

The code will need to be updated as SOFAR_FN_CHARGE and SOFAR_FN_DISCHARGE would be the same register but with a positive or negative value (negative=discharge, positive=charge).

I've just incorporated Andre's code to bring write support to the [Raspberry Pi version of sofar2mqtt](https://gitlab.com/rjpearce/sofar2mqtt/-/tree/write_support/).

joostvdveen, 2023-03-20:
hi all, I just tested a new version https://github.com/IgorYbema/Sofar2mqtt/tree/mod of https://github.com/IgorYbema/Sofar2mqtt (a fork of https://github.com/cmcgerty/Sofar2mqtt) on my Solar HYD EP and the Charge and Discharge commands from home assistant work in passive mode.

wardwygaerts, 2023-03-20:
> hi all, I just tested a new version https://github.com/IgorYbema/Sofar2mqtt/tree/mod

Can I just flash the bin file, or do I need to build the code?

Loudo42, 2023-04-18:
Hi,

I have tried the IgorYbema fork code for my HYD6000EP. To make it working, I add to change a little the code.
But it misses the command to set it up in automode.
In the sofar description, it is said to write the register 4368 with 01 10 11 10 00 01 02 00 00 A5 C1.
Does somebody know  how to implement it?

Moreover, I can only send 23 values with the sendmqtt command. When I add 1 line more in the mqtt_status_register, nothing is sent.
What is the issue, how can I solve it?

Thank you very much in advance.

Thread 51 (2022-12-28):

HYD 6000-ZSS HP receiving mqtt with zero on all values

megamarco833, 2022-12-28:
hello, i have an inverter model HYD 6000-ZSS HP and i flashed a wemoss D1 mini
```
//#define INVERTER_ME3000				// Uncomment for ME3000
#define INVERTER_HYBRID			// Uncomment for Hybrid
```

i'm using a TTL - RS485 generic (i'm waiting that MAX3485 will arrive)
https://ae01.alicdn.com/kf/H5299716877f943ae80442061597977df9.jpg
i connect
TTL-RS485  to  Wemos
 RX to D6
 TX to D7
 VCC to 3v3
 GND to GND

i see on oled: "standby" online
id i subscrive to Sofar2mqtt/state i see
`{"running_state":0,"grid_voltage":0,"grid_current":0,"grid_freq":0,"grid_power":0,"battery_power":0,"battery_voltage":0,"battery_current":0,"systemIO_power":0,"batterySOC":0,"battery_temp":0,"battery_cycles":0,"consumption":0,"solarPV":0,"solarPVAmps":0,"today_generation":0,"Solarpv1":0,"inverter_temp":0,"inverter_HStemp":0}`

so all vale are zero.

i have this plug and i connect my TTL RS485 to pin5 and pin6 of this plug (that's the only pin that display the message above)
and when i connect these two pins at main plug inside inverter display i see RS485 symbol in upper left corner
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

megamarco833, 2022-12-28:
i just notice that on OLED display on wemoss is showed:
```
sofar2mqtt
 online
 standby 
```

and after sometime just for a less then a second appear:
```
sofa2mqtt
 online
 RS485
 ERROR
```
then immediately the first message
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

https://user-images.githubusercontent.com/44502572/209865835-7e3bb270-5fda-476c-bf58-a841abf14b65.mp4

i also use arduino serial monitor and this is the log:

```
怘⸮ ⸮⸮⸮⸮⸮f⸮⸮ ~⸮⸮⸮⸮~  ~⸮⸮
WiFi connected - ESP IP address: 192.168.0.29
Attempting MQTT connection...connected
Set start up mode: Auto
Timeout waiting for RS485 response.
Response too short
Send heartbeat
Timeout waiting for RS485 response.
Response too short
Bad heartbeat -2
Get runstate: Timeout waiting for RS485 response.
Response too short
Response too short
Timeout waiting for RS485 response.
Response too short
Timeout waiting for RS485 response.
Response too short
Timeout waiting for RS485 response.
Timeout waiting for RS485 response.
Timeout waiting for RS485 response.
Timeout waiting for RS485 response.
Timeout waiting for RS485 response.
Timeout waiting for RS485 response.
Timeout waiting for RS485 response.
Timeout waiting for RS485 response.
Timeout waiting for RS485 response.
Timeout waiting for RS485 response.
Timeout waiting for RS485 response.
Timeout waiting for RS485 response.
Timeout waiting for RS485 response.
Timeout waiting for RS485 response.
Timeout waiting for RS485 response.
Timeout waiting for RS485 response.
Timeout waiting for RS485 response.
Timeout waiting for RS485 response.
Send heartbeat
Timeout waiting for RS485 response.
Response too short
Bad heartbeat -2
Get runstate: Timeout waiting for RS485 response.
0
Timeout waiting for RS485 response.
Timeout waiting for RS485 response.
Timeout waiting for RS485 response.
Timeout waiting for RS485 response.
Timeout waiting for RS485 response.
Timeout waiting for RS485 response.
Timeout waiting for RS485 response.
Timeout waiting for RS485 response.
Timeout waiting for RS485 response.
Timeout waiting for RS485 response.
Timeout waiting for RS485 response.
Timeout waiting for RS485 response.
Timeout waiting for RS485 response.
Timeout waiting for RS485 response.
Timeout waiting for RS485 response.
Timeout waiting for RS485 response.
Timeout waiting for RS485 response.
Timeout waiting for RS485 response.
Timeout waiting for RS485 response.
Timeout waiting for RS485 response.
Timeout waiting for RS485 response.
Attempting MQTT connection...connected
Send heartbeat
Timeout waiting for RS485 response.
Response too short
Bad heartbeat -2
Get runstate: Timeout waiting for RS485 response.
0
Timeout waiting for RS485 response.
Timeout waiting for RS485 response.
Timeout waiting for RS485 response.
Timeout waiting for RS485 response.
Timeout waiting for RS485 response.
Timeout waiting for RS485 response.
Timeout waiting for RS485 response.
Timeout waiting for RS485 response.
Timeout waiting for RS485 response.
Timeout waiting for RS485 response.
Timeout waiting for RS485 response.
Timeout waiting for RS485 response.
Timeout waiting for RS485 response.
Timeout waiting for RS485 response.
Timeout waiting for RS485 response.
Timeout waiting for RS485 response.
Timeout waiting for RS485 response.
Timeout waiting for RS485 response.
Timeout waiting for RS485 response.
Timeout waiting for RS485 response.
Timeout waiting for RS485 response.
Send heartbeat
Timeout waiting for RS485 response.
Response too short
Bad heartbeat -2
Get runstate: Timeout waiting for RS485 response.
0
Timeout waiting for RS485 response.
Timeout waiting for RS485 response.
Timeout waiting for RS485 response.
Timeout waiting for RS485 response.
Timeout waiting for RS485 response.
```

cliffdude, 2022-12-29:
Hi,

Do you have the pinout for that connector? It is possible that only *one*
of the RS485 wires is in the correct pin, sometimes that will "trick" the
inverter into thinking that an RS485 is in fact connected and will show the
symbol in the display. The RS485 symbol will disappear after about 30
secs... It has happened to me :)
I cannot help you with the pinout as I have a different model.

On Wed, Dec 28, 2022 at 8:00 PM megamarco833 ***@***.***>
wrote:

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

megamarco833, 2022-12-29:
> Hi, Do you have the pinout for that connector? It is possible that only *one* of the RS485 wires is in the correct pin, sometimes that will "trick" the inverter into thinking that an RS485 is in fact connected and will show the symbol in the display. The RS485 symbol will disappear after about 30 secs... It has happened to me :) I cannot help you with the pinout as I have a different model.

hello, thanks for your reply.
finally i talked with customer care and they told me that the protocol is changed since 2021 with new generation of inverters (V3) and now all inverters mono phase and 3 pahses have the new common protocol RS485 modbus with new addresses.
i find the new adresses and i try to chenge your code with new one and i receive the right response, but the numbers aren't diplay correctly.
example: grid_freq":5001  should be 50,01

this is the json where i just try to change some addresses with new ones
`{"running_state":0,"grid_voltage":0,"grid_current":0,"grid_freq":5001,"grid_power":5001,"battery_power":65534,"battery_voltage":491,"battery_current":65466,"systemIO_power":65466,"batterySOC":27,"battery_temp":20,"battery_cycles":0,"consumption":0,"solarPV":0,"solarPVAmps":0,"today_generation":0,"Solarpv1":0,"Solarpv2":0,"today_consumption":0,"inverter_temp":0,"inverter_HStemp":0}`

i see in documentation that new now they are using 16bit and not 8bit could be that the reason?

this below is a configuration for HA that i find:

```
 - name: "Frequenza di rete" #"ongrid_frequency"
    slave: 1
    address: 0x0484
    data_type: int16
    device_class: frequency
    unit_of_measurement: "Hz"
    scale: 0.01
    scan_interval: 10
    precision: 2
```

do you like to add the support also for the new generation inverter? :)

double1968, 2022-12-29:
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

For some values it is sufficient to change the scale value.
For other values such as battery power it is necessary to create template sensors to transform the value. You can find examples here too
[Configuration](https://github.com/cmcgerty/Sofar2mqtt/blob/main/Home%20Assistant%20example/configuration.yaml)

megamarco833, 2022-12-29:
> For some values it is sufficient to change the scale value. For other values such as battery power it is necessary to create template sensors to transform the value. You can find examples here too [Configuration](https://github.com/cmcgerty/Sofar2mqtt/blob/main/Home%20Assistant%20example/configuration.yaml)
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
double1968, 2022-12-30:
power and other data are returned with values to be processed with that formula.

megamarco833, 2023-01-27:
@cmcgerty this is the new protocol V3:
https://docs.google.com/spreadsheets/u/0/d/1p6p7n8-V2jlFid3FPPk5L4Sn4-tOWscQwpkahq5jRbs/htmlview#
seams that the new inverter has a new v3 protocol with new addresses

joostvdveen, 2023-03-15:
hi @megamarco833
I have a SOFAR HYD 5000-EP with software V030021

I encounter the same issue, no values in HA

what software version do you have?
And is the thing I need to do change the addresses to new ones?

megamarco833, 2023-03-15:
>

hello, my inverter is different model than yours, anyhow i discovered that the modbus protocol is different for new inverters, it has a different addresses.
in my case this was the reason why i was not able to get any value

joostvdveen, 2023-03-15:
@megamarco833

> hello, my inverter is different model than yours, anyhow i discovered that the modbus protocol is different for new inverters, it has a different addresses.
> in my case this was the reason why i was not able to get any value

So I do need to replace the used addresses in  the Solar2mqtt.ino file to new ones I have to lookup in the google spreadsheet??

```c++

// SoFar ME3000 Information Registers
#define SOFAR_REG_RUNSTATE	0x0200
#define SOFAR_REG_GRIDV		0x0206
#define SOFAR_REG_GRIDA		0x0207
#define SOFAR_REG_GRIDFREQ	0x0484
#define SOFAR_REG_BATTW		0x020d
#define SOFAR_REG_BATTV		0x020e
#define SOFAR_REG_BATTA		0x020f
#define SOFAR_REG_BATTSOC	0x0608
#define SOFAR_REG_BATTTEMP	0x0211
#define SOFAR_REG_GRIDW		0x0212
#define SOFAR_REG_LOADW		0x0213
#define SOFAR_REG_SYSIOW	0x0214
#define SOFAR_REG_PVW		0x0215
#define SOFAR_REG_PVDAY		0x0218
#define SOFAR_REG_EXPDAY	0x0219
#define SOFAR_REG_IMPDAY	0x021a
#define SOFAR_REG_LOADDAY	0x021b
#define SOFAR_REG_BATTCYC	0x022c
#define SOFAR_REG_PVA		0x0236
#define SOFAR_REG_INTTEMP	0x0238
#define SOFAR_REG_HSTEMP	0x0239
#define SOFAR_REG_PV1		0x0252
#define SOFAR_REG_PV2		0x0255
#define SOFAR_FN_STANDBY	0x0100
#define SOFAR_FN_DISCHARGE	0x0101
#define SOFAR_FN_CHARGE		0x0102
#define SOFAR_FN_AUTO		0x0103
```

joostvdveen, 2023-03-15:
I found another thread https://github.com/cmcgerty/Sofar2mqtt/discussions/57 I will ook into that

megamarco833, 2023-03-16:
....mine register are completely different:

```
//HYD 6000 ZSS HB -- V3 protocol
  #define SOFAR_REG_RUNSTATE  0x0404
  #define SOFAR_REG_GRIDV   0x048D
  #define SOFAR_REG_GRIDA   0x048E
  #define SOFAR_REG_GRIDFREQ  0x0484

  #define SOFAR_PV1_VOLT    0x0584
  #define SOFAR_PV1_CURR    0x0585
  #define SOFAR_PV1_POW     0x0586
  #define SOFAR_PV2_VOLT    0x0587
  #define SOFAR_PV2_CURR    0x0588
  #define SOFAR_PV2_POW     0x0589

  #define SOFAR_active_power     0x0485
  #define SOFAR_today_generation     0x0685
  #define SOFAR_total_generation     0x0687
  #define SOFAR_load_power_house     0x04AF  //AC on Grid output ==  ActivePower_Load_Sys
  #define SOFAR_load_power_pv_ext     0x04AE //ActivePower_PV_Ext
  #define SOFAR_load_power_out_tot      0x0485  //ActivePower_Output_Total
  #define SOFAR_load_power_pcc_tot      0x0488 //ActivePower_PCC_Total
  #define SOFAR_load_power_grid5      0x0506
  #define SOFAR_load_power_grid6      0x0507
  #define SOFAR_load_power_grid7      0x050A
  #define SOFAR_load_power_grid8      0x0524

  #define SOFAR_today_consumption     0x0689
  #define SOFAR_total_consumption     0x068B

  #define SOFAR_today_import     0x068D
  #define SOFAR_total_import     0x068F
  #define SOFAR_today_export     0x0691
  #define SOFAR_total_export     0x0693

  #define SOFAR_REG_BATTW   0x0606
  #define SOFAR_BATT_TEMP   0x0607
  #define SOFAR_BATT_CURR   0x0605
  #define SOFAR_BATT_VOLT   0x0604
  #define SOFAR_BATT_TDY_DISC   0x0699
  #define SOFAR_BATT_TDY_CHARG   0x0695
  #define SOFAR_BATT_SOC 0x0608    // SOC state of charge battery1== stato di carica in %
  #define SOFAR_BATT_SOC2 0x060F    // SOC state of charge battery2 == stato di carica in %
  #define SOFAR_BATT_HEALT 0x0609  //battery_soh
  #define SOFAR_BATT_CYCLES 0x060A
  #define SOFAR_REG_BATTW   0x0606
  #define SOFAR_REG_BATTV   0x0604
  #define SOFAR_REG_BATTA   0x0605
```

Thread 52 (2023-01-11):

setup resets the inverter to auto mode which may be undesirable

rbrooklyn, 2023-01-11:
Hi,

Firstly, LOVE this project! Had a blast figuring it out, doing the soldering and generally getting this thing to work.

I am noticing that the setup() function has the line:
sendPassiveCmd(SOFAR_SLAVE_ID, SOFAR_FN_AUTO, 0, "startup_auto");

Which will put the inverter into "auto" mode.

Why is this done? Odds are, the inverter would survive any power cut better than the microcontroller which is likely to be on mains electrics. Even if it was somehow _also_ connected to the EPS, there is a delay of several seconds, causing it to be rebooted in any case. Whatever mode the inverter was in might be the desired mode. I don't think the software should force this setting if it can be avoided.

Maybe this is required so the microcontroller can be in sync with the inverter and it's somehow not possible to read the setting from the inverter from a cold boot. But if it could be read from the inverter and set internally instead of being set from the microcontroller on start-up, then I feel that would be more desirable.

Again, loving your work. Thank you for making this.

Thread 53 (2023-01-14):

Can Sofar2mqtt be RS485 slave?

Simoverdex, 2023-01-14:
Hi folks, in the last few days I've added a wallbox for charging electric cars, which communicates with my inverter in RS485. I tried to connect my Sofar2mqtt together with the walbox, but being two Modbus Masters, I often receive incorrect values. Is there a possibility to make our Sofar2mqtt RS485 slave, so it would become a data "Sniffer"?

phamels, 2023-02-12:
Also interested to find out.
I noticed there is a slave port on the Sofar controller. Would it automatically become a slave without the ability to send data to it (just querying) or how would that work?
Anyone have any idea or more info on the slave port?

Simoverdex, 2023-02-12:
>

So, in a modbus network the master (in this case the logger) makes the request, while the slave (inverter) sends the data. In my situation I have two masters requesting data from a slave, and this situation generates errors.

phamels, 2023-02-12:
I have a similar issue where I want to use sofar2mqtt as a master, but a secondary device as a master as well.
Just confused with the fact that the sofar controller ME3000SP in my case, has a RS485 master and slave port.
So I guess the way around this would be if we could for example modify sofar2mqtt to act as a master, read the data and replay it to the second master? Just thinking out loud here.

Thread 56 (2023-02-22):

wrong order of if statement?

IgorYbema, 2023-02-22:
Should this be the other way around?
https://github.com/cmcgerty/Sofar2mqtt/blob/4f061801fb2c7e3699ccd78cc1b99fed54aead0d/Sofar2mqtt/Sofar2mqtt.ino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

cmcgerty, 2023-02-22:
Quite possibly. It certainly looks like p would only be set if readSingleReg fails. Do you have one connected with a serial console open? Does it constantly log “modbus error” when in battery save mode? I’ll take a look when I get a chance.

IgorYbema, 2023-02-22:
Not using batterysave but I just noticed it while modifying the code a bit to suit my own situation

david9600, 2025-05-27:
I know this thread dates back a couple of years, but as I had a similar thought when reading the code, I looked into it, and can confirm that the logic is OK as is.

The readSingleReg() function passes on the return code from sendModbus(), which in turn passes on the return code from listen(). That function listen() returns an errorLevel which is zero for a valid frame received, or non-zero otherwise.

So, if(readSingleReg) is equivalent to "if a bad frame is received", and if(!readSingleReg) is "if a valid frame is received", which is what's needed.  A bit confusing yes, but it seems OK, and is working in my ESP, which is the main thing :P)

Closed 2025-05-27.

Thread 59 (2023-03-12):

Compiling Errors with latest Arduino IDE 2.0.4

championc, 2023-03-12:
Hi there

When I take the code from the project, I get the following errors when compiling it - although it does compile, but can this reported errors be fixed ?

C:\Users\corma\Downloads\Sofar2mqtt\Sofar2mqtt.ino: In function 'int listen(modbusResponse*)':
C:\Users\corma\Downloads\Sofar2mqtt\Sofar2mqtt.ino:644:24: warning: ISO C++ forbids converting a string constant to 'char*' [-Wwrite-strings]
  644 |   resp->errorMessage = "Response too short";
      |                        ^~~~~~~~~~~~~~~~~~~~
C:\Users\corma\Downloads\Sofar2mqtt\Sofar2mqtt.ino:649:24: warning: ISO C++ forbids converting a string constant to 'char*' [-Wwrite-strings]
  649 |   resp->errorMessage = "Valid data frame";
      |                        ^~~~~~~~~~~~~~~~~~
C:\Users\corma\Downloads\Sofar2mqtt\Sofar2mqtt.ino:654:24: warning: ISO C++ forbids converting a string constant to 'char*' [-Wwrite-strings]
  654 |   resp->errorMessage = "Error: invalid data frame";
      |                        ^~~~~~~~~~~~~~~~~~~~~~~~~~~
c:\Users\corma\Documents\Arduino\libraries\Adafruit_SSD1306_Wemos_Mini_OLED\Adafruit_SSD1306.cpp: In member function 'void Adafruit_SSD1306::drawFastHLineInternal(int16_t, int16_t, int16_t, uint16_t)':
c:\Users\corma\Documents\Arduino\libraries\Adafruit_SSD1306_Wemos_Mini_OLED\Adafruit_SSD1306.cpp:612:21: warning: ISO C++17 does not allow 'register' storage class specifier [-Wregister]
  612 |   register uint8_t *pBuf = buffer;
      |                     ^~~~
c:\Users\corma\Documents\Arduino\libraries\Adafruit_SSD1306_Wemos_Mini_OLED\Adafruit_SSD1306.cpp:618:20: warning: ISO C++17 does not allow 'register' storage class specifier [-Wregister]
  618 |   register uint8_t mask = 1 << (y&7);
      |                    ^~~~
c:\Users\corma\Documents\Arduino\libraries\Adafruit_SSD1306_Wemos_Mini_OLED\Adafruit_SSD1306.cpp: In member function 'void Adafruit_SSD1306::drawFastVLineInternal(int16_t, int16_t, int16_t, uint16_t)':
c:\Users\corma\Documents\Arduino\libraries\Adafruit_SSD1306_Wemos_Mini_OLED\Adafruit_SSD1306.cpp:686:20: warning: ISO C++17 does not allow 'register' storage class specifier [-Wregister]
  686 |   register uint8_t y = __y;
      |                    ^
c:\Users\corma\Documents\Arduino\libraries\Adafruit_SSD1306_Wemos_Mini_OLED\Adafruit_SSD1306.cpp:687:20: warning: ISO C++17 does not allow 'register' storage class specifier [-Wregister]
  687 |   register uint8_t h = __h;
      |                    ^
c:\Users\corma\Documents\Arduino\libraries\Adafruit_SSD1306_Wemos_Mini_OLED\Adafruit_SSD1306.cpp:691:21: warning: ISO C++17 does not allow 'register' storage class specifier [-Wregister]
  691 |   register uint8_t *pBuf = buffer;
      |                     ^~~~
c:\Users\corma\Documents\Arduino\libraries\Adafruit_SSD1306_Wemos_Mini_OLED\Adafruit_SSD1306.cpp:698:20: warning: ISO C++17 does not allow 'register' storage class specifier [-Wregister]
  698 |   register uint8_t mod = (y&7);
      |                    ^~~
c:\Users\corma\Documents\Arduino\libraries\Adafruit_SSD1306_Wemos_Mini_OLED\Adafruit_SSD1306.cpp:706:22: warning: ISO C++17 does not allow 'register' storage class specifier [-Wregister]
  706 |     register uint8_t mask = premask[mod];
      |                      ^~~~
c:\Users\corma\Documents\Arduino\libraries\Adafruit_SSD1306_Wemos_Mini_OLED\Adafruit_SSD1306.cpp:744:24: warning: ISO C++17 does not allow 'register' storage class specifier [-Wregister]
  744 |       register uint8_t val = (color == WHITE) ? 255 : 0;
      |                        ^~~
c:\Users\corma\Documents\Arduino\libraries\Adafruit_SSD1306_Wemos_Mini_OLED\Adafruit_SSD1306.cpp:766:22: warning: ISO C++17 does not allow 'register' storage class specifier [-Wregister]
  766 |     register uint8_t mask = postmask[mod];
      |                      ^~~~

joostvdveen, 2023-03-16:
I have the same issue

OGB1952, 2023-03-21:
Same here, too.  The previous version of Sofar2mqtt was fine, seems to compile without errors.  I'm only getting the compile warnings in the CRC section, though, but that may be because I'm using a different display.

JonathanJ71, 2023-05-04:
Is somebody have a compilable version for ide 2?

nejib1, 2023-08-18:
Just comment these lines... no need of them

davergu, 2024-02-25:
Has this been resolved? I have tried various versions of Arduino IDE and Sofar2mqtt and none have worked. I've not attempted older libraries as the permutations are legion. Does anyone know the required permutation of everything?!

rbrooklyn, 2025-05-31:
It compiles fine, you do need to ensure you have installed specific versions of the libraries and not the latest versions which have introduced breaking changes.

I have compiled this project today successfully using Arduino IDE 2.3.6 and these libraries and versions:
Adafruit BusIO 1.14.1
Adafruit GFX Library 1.12.1
Adafruit SSD1306 Wemos Mini OLED 1.1.2
PubSubClient 2.8
And these boards and versions:
Arduino AVR Boards 1.8.6
esp8266 3.0.2

david9600, 2025-05-31:
My experience with current libraries was that the compilation completed, but with 3 warnings in the listen() function relating to the conversion of string to a char pointer.
While the warnings didn't prevent loading the code, I eventually researched the errors with the aim of clean compilation, and was able to modify the code to that below, which converts the string before insertion into the array.  In my IDE at least, it now runs cleanly!

	String str;
	if(inFrameSize < 5)
	{
		resp->errorLevel = 2;
		str = "Response too short";
	}
	else if(checkCRC(inFrame, inFrameSize))
	{
		resp->errorLevel = 0;
		str = "Valid data frame";
	}
	else
	{
		resp->errorLevel = 1;
		str = "Error: invalid data frame";
	}
	//convert string to char*
	std::vector<char> cstr(str.begin(), str.end());
	resp->errorMessage = cstr.data();

        return -resp->errorLevel;

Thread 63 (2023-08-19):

How to stop charge ?

nejib1, 2023-08-19:
Hello,

After charging the battery using Sofar2mqtt (It works fine), I tried to stop charging in Home Assistant by putting
Sofar2mqtt/set/auto like this :
`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

But it seems that the message is sent unlimited time to the inverter, is there a clean way to stop charging once ?

Thank you in advance.
`

FFV21, 2023-11-29:
I was looking for a way to stop charging/discharging the battery through Home Assistant as well and this seems to work for me;
publish to the topic /set/standby instead of /set/auto

```service: mqtt.publish
data:
  qos: "1"
  retain: false
  topic: Sofar2MQTT/set/standby
  payload: "true"
```

Have only just started looking into this but from the limited testing I have done that puts the battery in standby ie not charging/not discharging

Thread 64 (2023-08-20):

Inverter mode change

Romainiak, 2023-08-20:
Dear Authors

My parents live in South Africa where power outages/loadshedding is common and I have recently purchased a Sofar hyd 6000-Ep for them. In South Africa power is not that exspensive but batteries are.

I want the inverter not to run the default of PV-Battery-Grid always charging and discharging the battery but to run PV-Grid-battery so that the battery is always charged but only is used when the grid goes down. I believe the timing functions should allow this but I do not know if the timing function will stop the inverter using battery power if the grid goes down during this schedule?

Will your mod be able to be programmed to force the inverter to run the battery at full charge and in standby untill the grid goes off and once the grid comes back on then charges the battery with pv or grid?

The idea again is to save the batteries from exessively using charge cycles.

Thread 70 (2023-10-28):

Recovery of product power only

stephcache, 2023-10-28:
Hello, I have seen your code and I cannot modify it in order to recover only the power produced in order to turn on my water heater, heating.

[https://forum.arduino.cc/t/rs485-et-sofar-solar/1180679](url)

I would really like some help to retrieve this information only, I don't need a home assistant

cliffdude, 2023-10-29:
You can try my fork, it is of an older version however you can get the data
you need in JSON format.
https://github.com/cliffdude/SofarCtrl

You will need to multiply the solarPV by 10 and ignore the rest of the data
in the JSON string.

Good luck

[image: image.png]

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

stephcache, 2023-10-29:
Your link looks a lot like the other one. I don't need oled, nor mqtt, nor json and I use an esp32 not an esp8266.

In addition <SoftwareSerial.h> is not visible, not compatible with esp32.

I am looking for the power produced by the instantaneous panels.

I can't find any information to just read the registers that come in HYD 6000-EP

cliffdude, 2023-10-29:
If you want to use an ESP32 you will have to modify the code yourself, the
info for the registers is in the code on Colin's repo, my fork is not
compatible with the EP version of the inverter  ( I have the older ES).
I would suggest creating a repo targeted at the ESP32 board, look through
the code and you will find the section that communicates with the inverter,
that is all you need. Extract it and use it in your own code.

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

stephcache, 2023-10-29:
I go through them, and I can't find the part that communicates with the inverter (I don't understand would be more accurate). That’s why I’m asking the question.

cliffdude, 2023-10-29:
Line 543 to 700 contains most of the code, you will need to read it to
understand what is going on.

https://github.com/cmcgerty/Sofar2mqtt/blob/main/Sofar2mqtt/Sofar2mqtt.ino

Check out the pull requests as there is more info on the registers for the
EP.
 I did not write this code and have little experience with modbus so I
cannot help you more.

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

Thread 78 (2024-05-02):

Sofar MQTT

chaosnature, 2024-05-02:
Hi,

i followed your directions and have succeeded in plugging the devices as stated above - but i am stuck in 2 aspect at the moment.

1.

I downloaded the Format but how and where is the config for the Sofar2mqtt and Emonoms Sofarmqtt ?

Mine looks like this at the momenet

2.

How does the device connect to the sofar inverter.....i dont see any wires - or is it via BLE then how?

many thanks and keep up the good work
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

regards

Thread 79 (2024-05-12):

Board does not connect to inverter

Crapoto94, 2024-05-12:
Hi all, and sorry for my bad english :)
My sofar2mqtt is not connecting to the inverter.
The serial monitor show : "Timeout waiting for RS485 response."
For compiling, i changed D6 in 12, D7 in 13 and D5 in 14.
I can see the RS485 logo on the inverter, but the LED display CRC-FAULT ERROR.
I tried to invert the wires, the logo is still there, but il's stll not working.
I changed the MAX485 board, same issue. There is a red light on the board.
Can anibody help me ?

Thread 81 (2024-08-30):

Potential Predbat Interwork issue

dbw1966, 2024-08-30:
See Predbat issue #1407.

Inconsistent PV today data spotted, coincident with logs in HA showing for example

2024-08-29 18:37:15.405 WARNING (MainThread) [homeassistant.helpers.template] Template variable warning: 'dict object' has no attribute 'solarPVAmps' when rendering '{{ value_json.solarPVAmps }}'
2024-08-29 19:37:16.917 WARNING (MainThread) [homeassistant.helpers.template] Template variable warning: 'dict object' has no attribute 'batterySOC' when rendering '{{ value_json.batterySOC }}'

Logfile attached.
[HA Log DW 240830 1008.txt](https://github.com/user-attachments/files/16814850/HA.Log.DW.240830.1008.txt)

Maybe error handling at Predbat not accurate?

dbw1966, 2024-08-31:
Someone on FB pointed to an error in the code for sofar2mqtt.  The last lines read

bool checkCRC(uint8_t frame[], byte frameSize)
{
	unsigned int calculated_crc, received_crc;

	received_crc = ((frame[frameSize-2] << 8) | frame[frameSize-1]);
	calcCRC(frame, frameSize);
	calculated_crc = ((frame[frameSize-2] << 8) | frame[frameSize-1]);
	return (received_crc = calculated_crc);
}

And they should have read
bool checkCRC(uint8_t frame[], byte frameSize)
{
	unsigned int calculated_crc, received_crc;

	received_crc = ((frame[frameSize-2] << 8) | frame[frameSize-1]);
	calcCRC(frame, frameSize);
	calculated_crc = ((frame[frameSize-2] << 8) | frame[frameSize-1]);
	return (received_crc == calculated_crc);
}

== is the comparitor that should have been used.

I will see if this fixes it.

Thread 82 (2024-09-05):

Grid current is not grid current

jacoscar, 2024-09-05:
Hello, I just realised the "grid current" sensor is not what one would think.
I always thought it was the current measured by the clamp (imported or exported at the house main meter), but it's just the current on the grid input of the inverter. Is there a way to get the current measured by the CT clamp at the main meter?

david9600, 2025-05-28:
Hi, I know this query dates back a few months, but if you haven't already sorted it, there's a document called "SOFARSOLAR ModBus-RTU Communication Protocol", which can be found on the net, and shows these register addresses:
Grid A current 0x0207  (A, B, C being 3 phase at the inverter)
Grid R current 0x0231  (R, S, T should be the 3 phases at the grid meter connection, from a CT or RS485 input to the inverter)
So I'd suggest trying that one.

I had to go through a similar process to identify the registers for my inverter - a newer series with addresses in the 0x4xxx range, so in my case it was necessary to change ALL the addresses in the code!

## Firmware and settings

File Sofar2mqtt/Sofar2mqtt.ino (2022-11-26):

// Update these to match your inverter/network.
#define INVERTER_ME3000				// Uncomment for ME3000
//#define INVERTER_HYBRID			// Uncomment for Hybrid

// The device name is used as the MQTT base topic. If you need more than one Sofar2mqtt on your network, give them unique names.
const char* deviceName = "Sofar2mqtt";
const char* version = "v2.1.1";

#define WIFI_SSID	"xxxxx"
#define WIFI_PASSWORD	"xxxxx"
#define MQTT_SERVER	"mqtt"
#define MQTT_PORT	1883
#define MQTT_USERNAME	"auser"			// Empty string for none.
#define MQTT_PASSWORD	"apassword"

/*****
Sofar2mqtt is a remote control interface for Sofar solar and battery inverters.
It allows remote control of the inverter and reports the invertor status, power usage, battery state etc for integration with smart home systems such as Home Assistant and Node-Red vi MQTT.  
For read only mode, it will send status messages without the inverter needing to be in passive mode.  
It's designed to run on an ESP8266 microcontroller with a TTL to RS485 module such as MAX485 or MAX3485.  
Designed to work with TTL modules with or without the DR and RE flow control pins. If your TTL module does not have these pins then just ignore the wire from D5. 

Subscribe your MQTT client to:

Sofar2mqtt/state

Which provides:

running_state  
grid_voltage  
grid_current  
grid_freq
systemIO_power (AC side of inverter) 
battery_power  (DC side of inverter)
battery_voltage  
battery_current
batterySOC  
battery_temp  
battery_cycles  
grid_power  
consumption  
solarPV  
today_generation  
today_exported  
today_purchase  
today_consumption  
inverter_temp  
inverterHS_temp  
solarPVAmps
  

With the inverter in Passive Mode, send MQTT messages to:

Sofar2mqtt/set/standby   - send value "true"
Sofar2mqtt/set/auto   - send value "true" or "battery_save"
Sofar2mqtt/set/charge   - send values in the range 0-3000 (watts)
Sofar2mqtt/set/discharge   - send values in the range 0-3000 (watts)

Each of the above will return a response on:
Sofar2mqtt/response/<function>, the message containing the response from
the inverter, which has a result code in the lower byte and status in the upper byte.

The result code will be 0 for success, 1 means "Invalid Work Mode" ( which possibly means
the inverter isn't in passive mode, ) and 3 means "Inverter busy." 2 and 4 are data errors
which shouldn't happen unless there's a cable issue or some such.

The status bits in the upper byte indicate the following:
Bit 0 - Charge enabled
Bit 1 - Discharge enabled
Bit 2 - Battery full, charge prohibited
Bit 3 - Battery flat, discharge prohibited

For example, a publish to Sofar2mqtt/set/charge will result in one on Sofar2mqtt/response/charge.
AND the message with 0xff to get the result code, which should be 0.

battery_save is a hybrid auto mode that will charge from excess solar but not discharge.

There will also be messages published to Sofar2mqtt/response/<type> when things happen
in the background, such as setting auto mode on startup and switching modes in battery_save mode.

(c)Colin McGerty 2021 colin@mcgerty.co.uk
Major version 2.0 rewrite by Adam Hill sidepipeukatgmaildotcom
Thanks to Rich Platts for hybrid model code and testing.
calcCRC by angelo.compagnucci@gmail.com and jpmzometa@gmail.com
*****/
#if (! defined INVERTER_ME3000) && ! defined INVERTER_HYBRID
#error You must specify the inverter type.
#endif

#include <Arduino.h>

#define SOFAR_SLAVE_ID          0x01

#ifdef INVERTER_ME3000
#define	MAX_POWER		3000		// ME3000 is 3000W max.
#elif defined INVERTER_HYBRID
#define MAX_POWER		6000
#endif

#define RS485_TRIES 8       // x 50mS to wait for RS485 input chars.
// Wifi parameters.
#include <ESP8266WiFi.h>
const char* wifiName = WIFI_SSID;
WiFiClient wifi;

// MQTT parameters
#include <PubSubClient.h>
const char* mqttClientID = deviceName;
PubSubClient mqtt(wifi);

// SoftwareSerial is used to create a second serial port, which will be deidcated to RS485.
// The built-in serial port remains available for flashing and debugging.
#include <SoftwareSerial.h>
#define SERIAL_COMMUNICATION_CONTROL_PIN D5 // Transmission set pin
#define RS485_TX HIGH
#define RS485_RX LOW
#define RXPin        D6  // Serial Receive pin
#define TXPin        D7  // Serial Transmit pin
SoftwareSerial RS485Serial(RXPin, TXPin);

// Sofar run states
#define waiting 0
#define check 1

#ifdef INVERTER_ME3000
#define charging		2
#define checkDischarge		3
#define discharging		4
#define epsState		5
#define faultState		6
#define permanentFaultState	7

#define HUMAN_CHARGING		"Charging"
#define HUMAN_DISCHARGING	"Discharge"

#elif defined INVERTER_HYBRID
#define normal			2
#define epsState		3
#define faultState		4
#define permanentFaultState	5
#define normal1			6

// State names are a bit strange - makes sense to also match to these?
#define charging		2
#define discharging		6

#define HUMAN_CHARGING		"Normal"
#define HUMAN_DISCHARGING	"Normal1"
#endif

#define MAX_FRAME_SIZE          64
#define MODBUS_FN_READSINGLEREG 0x03
#define SOFAR_FN_PASSIVEMODE    0x42
#define SOFAR_PARAM_STANDBY     0x5555

unsigned int INVERTER_RUNNINGSTATE;

// Battery Save mode is a hybrid mode where the battery will charge from excess solar but not discharge.
bool BATTERYSAVE = false;

// SoFar ME3000 Information Registers
#define SOFAR_REG_RUNSTATE	0x0200
#define SOFAR_REG_GRIDV		0x0206
#define SOFAR_REG_GRIDA		0x0207
#define SOFAR_REG_GRIDFREQ	0x020c
#define SOFAR_REG_BATTW		0x020d
#define SOFAR_REG_BATTV		0x020e
#define SOFAR_REG_BATTA		0x020f
#define SOFAR_REG_BATTSOC	0x0210
#define SOFAR_REG_BATTTEMP	0x0211
#define SOFAR_REG_GRIDW		0x0212
#define SOFAR_REG_LOADW		0x0213
#define SOFAR_REG_SYSIOW	0x0214
#define SOFAR_REG_PVW		0x0215
#define SOFAR_REG_PVDAY		0x0218
#define SOFAR_REG_EXPDAY	0x0219
#define SOFAR_REG_IMPDAY	0x021a
#define SOFAR_REG_LOADDAY	0x021b
#define SOFAR_REG_BATTCYC	0x022c
#define SOFAR_REG_PVA		0x0236
#define SOFAR_REG_INTTEMP	0x0238
#define SOFAR_REG_HSTEMP	0x0239
#define SOFAR_REG_PV1		0x0252
#define SOFAR_REG_PV2		0x0255

#define SOFAR_FN_STANDBY	0x0100
#define SOFAR_FN_DISCHARGE	0x0101
#define SOFAR_FN_CHARGE		0x0102
#define SOFAR_FN_AUTO		0x0103

struct mqtt_status_register
{
	uint16_t regnum;
	String    mqtt_name;
};

static struct mqtt_status_register  mqtt_status_reads[] =
{
	{ SOFAR_REG_RUNSTATE, "running_state" },
	{ SOFAR_REG_GRIDV, "grid_voltage" },
	{ SOFAR_REG_GRIDA, "grid_current" },
	{ SOFAR_REG_GRIDFREQ, "grid_freq" },
	{ SOFAR_REG_GRIDW, "grid_power" },
	{ SOFAR_REG_BATTW, "battery_power" },
	{ SOFAR_REG_BATTV, "battery_voltage" },
	{ SOFAR_REG_BATTA, "battery_current" },
	{ SOFAR_REG_SYSIOW, "systemIO_power" },
	{ SOFAR_REG_BATTSOC, "batterySOC" },
	{ SOFAR_REG_BATTTEMP, "battery_temp" },
	{ SOFAR_REG_BATTCYC, "battery_cycles" },
	{ SOFAR_REG_LOADW, "consumption" },
	{ SOFAR_REG_PVW, "solarPV" },
	{ SOFAR_REG_PVA, "solarPVAmps" },
	{ SOFAR_REG_PVDAY, "today_generation" },
#ifdef INVERTER_ME3000
	{ SOFAR_REG_EXPDAY, "today_exported" },
	{ SOFAR_REG_IMPDAY, "today_purchase" },
#elif defined INVERTER_HYBRID
	{ SOFAR_REG_PV1, "Solarpv1" },
	{ SOFAR_REG_PV2, "Solarpv2" },
#endif
	{ SOFAR_REG_LOADDAY, "today_consumption" },
	{ SOFAR_REG_INTTEMP, "inverter_temp" },
	{ SOFAR_REG_HSTEMP, "inverter_HStemp" },
};

// This is the return object for the sendModbus() function. Since we are a modbus master, we
// are primarily interested in the responses to our commands.
struct modbusResponse
{
	uint8_t errorLevel;
	uint8_t data[MAX_FRAME_SIZE];
	uint8_t dataSize;
	char* errorMessage;
};

// These timers are used in the main loop.
#define HEARTBEAT_INTERVAL 9000
#define RUNSTATE_INTERVAL 5000
#define SEND_INTERVAL 10000
#define BATTERYSAVE_INTERVAL 3000

// Wemos OLED Shield set up. 64x48, pins D1 and D2
#include <SPI.h>
#include <Wire.h>
#include <Adafruit_GFX.h>
#include <Adafruit_SSD1306.h>
#define OLED_RESET 0  // GPIO0
Adafruit_SSD1306 display(OLED_RESET);

/**
 * Check to see if the elapsed interval has passed since the passed in
 * millis() value. If it has, return true and update the lastRun. Note
 * that millis() overflows after 50 days, so we need to deal with that
 * too... in our case we just zero the last run, which means the timer
 * could be shorter but it's not critical... not worth the extra effort
 * of doing it properly for once in 50 days.
 */
bool checkTimer(unsigned long *lastRun, unsigned long interval)
{
	unsigned long now = millis();

	if(*lastRun > now)
		*lastRun = 0;

	if(now >= *lastRun + interval)
	{
		*lastRun = now;
		return true;
	}

	return false;
}

// Update the OLED. Use "NULL" for no change or "" for an empty line.
String oledLine1;
String oledLine2;
String oledLine3;
String oledLine4;

void updateOLED(String line1, String line2, String line3, String line4)
{
	display.clearDisplay();
	display.setTextSize(1);
	display.setTextColor(WHITE);
	display.setCursor(0,0);

	if(line1 != "NULL")
	{
		display.println(line1);
		oledLine1 = line1;
	}
	else
		display.println(oledLine1);

	display.setCursor(0,12);

	if(line2 != "NULL")
	{
		display.println(line2);
		oledLine2 = line2;
	}
	else
		display.println(oledLine2);

	display.setCursor(0,24);

	if(line3 != "NULL")
	{
		display.println(line3);
		oledLine3 = line3;
	}
	else
		display.println(oledLine3);

	display.setCursor(0,36);

	if(line4 != "NULL")
	{
		display.println(line4);
		oledLine4 = line4;
	}
	else
		display.println(oledLine4);

	display.display();
}

// Connect to WiFi
void setup_wifi()
{
	// We start by connecting to a WiFi network
	Serial.println();
	Serial.print("Connecting to ");
	Serial.println(wifiName);
	updateOLED("NULL", "NULL", "WiFi..", "NULL");
	WiFi.mode(WIFI_STA);
	WiFi.begin(wifiName, WIFI_PASSWORD);

	while (WiFi.status() != WL_CONNECTED)
	{
		delay(500);
		Serial.print(".");
		updateOLED("NULL", "NULL", "WiFi...", "NULL");
	}

	WiFi.hostname(deviceName);
	Serial.println("");
	Serial.print("WiFi connected - ESP IP address: ");
	Serial.println(WiFi.localIP());
	updateOLED("NULL", "NULL", "WiFi....", "NULL");
}

int addStateInfo(String &state, uint16_t reg, String human)
{
	unsigned int	val;
	modbusResponse	rs;

	if(readSingleReg(SOFAR_SLAVE_ID, reg, &rs))
		return -1;

	val = ((rs.data[0] << 8) | rs.data[1]);

	if (!( state == "{"))
		state += ",";

	state += "\"" + human + "\":" + String(val);
	return 0;
}

void sendData()
{
	static unsigned long	lastRun = 0;

	// Update all parameters and send to MQTT.
	if(checkTimer(&lastRun, SEND_INTERVAL))
	{
		int	l;
		String	state = "{";

		for(l = 0; l < sizeof(mqtt_status_reads)/sizeof(struct mqtt_status_register); l++)
			addStateInfo(state, mqtt_status_reads[l].regnum, mqtt_status_reads[l].mqtt_name);

		state = state+"}";

		//Prefix the mqtt topic name with deviceName.
		String topic(deviceName);
		topic += "/state";
		sendMqtt(const_cast<char*>(topic.c_str()), state);
	}
}

// This function is executed when an MQTT message arrives on a topic that we are subscribed to.
void mqttCallback(String topic, byte *message, unsigned int length)
{
	if(!topic.startsWith(String(deviceName) + "/set/"))
		return;

	Serial.print("Message arrived on topic: ");
	Serial.print(topic);
	Serial.print(". Message: ");
	String messageTemp;
	uint16_t fnCode = 0, fnParam = 0;
	String cmd = topic.substring(topic.lastIndexOf("/") + 1);

	for(int i = 0; i < length; i++)
	{
		Serial.print((char)message[i]);
		messageTemp += (char)message[i];
	}

	Serial.println();
	int   messageValue = messageTemp.toInt();
	bool  messageBool = ((messageTemp != "false") && (messageTemp != "battery_save"));

	if(cmd == "standby")
	{
		if(messageBool)
		{
			fnCode = SOFAR_FN_STANDBY;
			fnParam = SOFAR_PARAM_STANDBY;
		}
	}
	else if(cmd == "auto")
	{
		if(messageBool)
			fnCode = SOFAR_FN_AUTO;
		else if(messageTemp == "battery_save")
			BATTERYSAVE = true;
	}
	else if((messageValue > 0) && (messageValue <= MAX_POWER))
	{
		fnParam = messageValue;

		if(cmd == "charge")
			fnCode = SOFAR_FN_CHARGE;
		else if(cmd == "discharge")
			fnCode = SOFAR_FN_DISCHARGE;
	}

	if(fnCode)
	{
		BATTERYSAVE = false;
		sendPassiveCmd(SOFAR_SLAVE_ID, fnCode, fnParam, cmd);
	}
}

void batterySave()
{
	static unsigned long	lastRun = 0;

	if(checkTimer(&lastRun, BATTERYSAVE_INTERVAL) && BATTERYSAVE)
	{
		modbusResponse  rs;

		//Get grid power
		unsigned int	p = 0;

		if(!readSingleReg(SOFAR_SLAVE_ID, SOFAR_REG_GRIDW, &rs))
			p = ((rs.data[0] << 8) | rs.data[1]);
		else
			Serial.println("modbus error");

		Serial.print("Grid power: ");
		Serial.println(p);
		Serial.print("Battery save mode: ");

		// Switch to auto when any power flows to the grid.
		// We leave a little wriggle room because once you start charging the battery,
		// gridPower should be floating just above or below zero.
		if((p < 65535/2 || p > 65525) && (INVERTER_RUNNINGSTATE != discharging))
		{
			//exporting to the grid
			if(!sendPassiveCmd(SOFAR_SLAVE_ID, SOFAR_FN_AUTO, 0, "bsave_auto"))
				Serial.println("auto");
		}
		else
		{
			//importing from the grid
			if(!sendPassiveCmd(SOFAR_SLAVE_ID, SOFAR_FN_STANDBY, SOFAR_PARAM_STANDBY, "bsave_standby"))
				Serial.println("standby");
		}
	}
}

// This function reconnects the ESP8266 to the MQTT broker
void mqttReconnect() 
{
	// Loop until we're reconnected
	while(true)
	{
		mqtt.disconnect();		// Just in case.
		delay(200);
		Serial.print("Attempting MQTT connection...");
		updateOLED("NULL", "connecting", "NULL", "MQTT.");
		delay(500);
		updateOLED("NULL", "NULL", "NULL", "MQTT..");

		// Attempt to connect
		if(mqtt.connect(mqttClientID, MQTT_USERNAME, MQTT_PASSWORD))
		{
			Serial.println("connected");
			delay(1000);
			updateOLED("NULL", "NULL", "NULL", "MQTT....");
			delay(1000);

			//Set topic names to include the deviceName.
			String standbyMode(deviceName);
			standbyMode += "/set/standby";
			String autoMode(deviceName);
			autoMode += "/set/auto";
			String chargeMode(deviceName);
			chargeMode += "/set/charge";
			String dischargeMode(deviceName);
			dischargeMode += "/set/discharge";

			// Subscribe or resubscribe to topics.
			if(
				mqtt.subscribe(const_cast<char*>(standbyMode.c_str())) &&
				mqtt.subscribe(const_cast<char*>(autoMode.c_str())) &&
				mqtt.subscribe(const_cast<char*>(chargeMode.c_str())) &&
				mqtt.subscribe(const_cast<char*>(dischargeMode.c_str())))
			{
				updateOLED("NULL", "NULL", "NULL", "");
				break;
			}
		}

		Serial.print("failed, rc=");
		Serial.print(mqtt.state());
		Serial.println(" try again in 5 seconds");
		updateOLED("NULL", "NULL", "NULL", "MQTT...");

		// Wait 5 seconds before retrying
		delay(5000);
	}
}

/**
 * Flush the RS485 buffers in both directions. The doc for Serial.flush() implies it only
 * flushes outbound characters now... I assume RS485Serial is the same.
 */
void flushRS485()
{
	RS485Serial.flush();
	delay(200);

	while(RS485Serial.available())
		RS485Serial.read();
}

int sendModbus(uint8_t frame[], byte frameSize, modbusResponse *resp)
{
	//Calculate the CRC and overwrite the last two bytes.
	calcCRC(frame, frameSize);

	// Make sure there are no spurious characters in the in/out buffer.
	flushRS485();

	//Send
	digitalWrite(SERIAL_COMMUNICATION_CONTROL_PIN, RS485_TX);
	RS485Serial.write(frame, frameSize);

	// It's important to reset the SERIAL_COMMUNICATION_CONTROL_PIN as soon as
	// we finish sending so that the serial port can start to buffer the response.
	digitalWrite(SERIAL_COMMUNICATION_CONTROL_PIN, RS485_RX);
	return listen(resp);
}

// Listen for a response.
int listen(modbusResponse *resp)
{
	uint8_t		inFrame[64];
	uint8_t		inByteNum = 0;
	uint8_t		inFrameSize = 0;
	uint8_t		inFunctionCode = 0;
	uint8_t		inDataBytes = 0;
	int		done = 0;
	modbusResponse	dummy;

	if(!resp)
		resp = &dummy;      // Just in case we ever want to interpret here.

	resp->dataSize = 0;
	resp->errorLevel = 0;

	while((!done) && (inByteNum < sizeof(inFrame)))
	{
		int tries = 0;

		while((!RS485Serial.available()) && (tries++ < RS485_TRIES))
			delay(50);

		if(tries >= RS485_TRIES)
		{
			Serial.println("Timeout waiting for RS485 response.");
			break;
		}

		inFrame[inByteNum] = RS485Serial.read();

		//Process the byte
		switch(inByteNum)
		{
			case 0:
				if(inFrame[inByteNum] != SOFAR_SLAVE_ID)   //If we're looking for the first byte but it dosn't match the slave ID, we're just going to drop it.
					inByteNum--;          // Will be incremented again at the end of the loop.
				break;

			case 1:
				//This is the second byte in a frame, where the function code lives.
				inFunctionCode = inFrame[inByteNum];
				break;

			case 2:
				//This is the third byte in a frame, which tells us the number of data bytes to follow.
				if((inDataBytes = inFrame[inByteNum]) > sizeof(inFrame))
				inByteNum = -1;       // Frame is too big?
				break;

			default:
				if(inByteNum < inDataBytes + 3)
				{
					//This is presumed to be a data byte.
					resp->data[inByteNum - 3] = inFrame[inByteNum];
					resp->dataSize++;
				}
				else if(inByteNum > inDataBytes + 3)
					done = 1;
		}

		inByteNum++;
	}

	inFrameSize = inByteNum;

	/**
	* Now check to see if the last two bytes are a valid CRC.
	* If we don't have a response pointer we don't care.
	**/
	if(inFrameSize < 5)
	{
		resp->errorLevel = 2;
		resp->errorMessage = "Response too short";
	}
	else if(checkCRC(inFrame, inFrameSize))
	{
		resp->errorLevel = 0;
		resp->errorMessage = "Valid data frame";
	}
	else
	{
		resp->errorLevel = 1;
		resp->errorMessage = "Error: invalid data frame";
	}

	if(resp->errorLevel)
		Serial.println(resp->errorMessage);

	return -resp->errorLevel;
}

int readSingleReg(uint8_t id, uint16_t reg, modbusResponse *rs)
{
	uint8_t	frame[] = { id, MODBUS_FN_READSINGLEREG, reg >> 8, reg & 0xff, 0, 0x01, 0, 0 };

	return sendModbus(frame, sizeof(frame), rs);
}

int sendPassiveCmd(uint8_t id, uint16_t cmd, uint16_t param, String pubTopic)
{
	modbusResponse	rs;
	uint8_t	frame[] = { id, SOFAR_FN_PASSIVEMODE, cmd >> 8, cmd & 0xff, param >> 8, param & 0xff, 0, 0 };
	int		err = -1;
	String		retMsg;

	if(sendModbus(frame, sizeof(frame), &rs))
		retMsg = rs.errorMessage;
	else if(rs.dataSize != 2)
		retMsg = "Reponse is " + String(rs.dataSize) + " bytes?";
	else
	{
		retMsg = String((rs.data[0] << 8) | (rs.data[1] & 0xff));
		err = 0;
	}

	String topic(deviceName);
	topic += "/response/" + pubTopic;
	sendMqtt(const_cast<char*>(topic.c_str()), retMsg);
	return err;
}

void sendMqtt(char* topic, String msg_str)
{
	char	msg[1000];

	mqtt.setBufferSize(512);
	msg_str.toCharArray(msg, msg_str.length() + 1); //packaging up the data to publish to mqtt

	if (!(mqtt.publish(topic, msg)))
		Serial.println("MQTT publish failed");
}

void heartbeat()
{
	static unsigned long  lastRun = 0;

	//Send a heartbeat
	if(checkTimer(&lastRun, HEARTBEAT_INTERVAL))
	{
		uint8_t	sendHeartbeat[] = {SOFAR_SLAVE_ID, 0x49, 0x22, 0x01, 0x22, 0x02, 0x00, 0x00};
		int	ret;

		Serial.println("Send heartbeat");

		// This just makes the dot on the first line of the OLED screen flash on and off with
		// the heartbeat and clears any previous RS485 error massage that might still be there.
		if(!(ret = sendModbus(sendHeartbeat, sizeof(sendHeartbeat), NULL)))
		{
			String flashDot;

			if (oledLine2 == "Online")
				flashDot = "Online.";

			if (oledLine2 == "Online.")
				flashDot = "Online";

			if (oledLine3 == "RS485")
				oledLine3 = "";

			if (oledLine4 == "ERROR")
				oledLine4 = "";

			updateOLED("NULL", flashDot, "NULL", "NULL");
		}
		else
		{
			Serial.print("Bad heartbeat ");
			Serial.println(ret);
			updateOLED("NULL", "NULL", "RS485", "ERROR");
		}

		//Flash the LED
		digitalWrite(LED_BUILTIN, LOW);
		delay(4);
		digitalWrite(LED_BUILTIN, HIGH);
	}
}

void updateRunstate()
{
	static unsigned long	lastRun = 0;

	//Check the runstate
	if(checkTimer(&lastRun, RUNSTATE_INTERVAL))
	{
		modbusResponse  response;

		Serial.print("Get runstate: ");

		if(!readSingleReg(SOFAR_SLAVE_ID, SOFAR_REG_RUNSTATE, &response))
		{
			INVERTER_RUNNINGSTATE = ((response.data[0] << 8) | response.data[1]);
			Serial.println(INVERTER_RUNNINGSTATE);

			switch(INVERTER_RUNNINGSTATE)
			{
				case waiting:
					if (BATTERYSAVE)
						updateOLED("NULL", "NULL", "Batt Save", "Waiting");
					else
						updateOLED("NULL", "NULL", "Standby", "");
					break;

				case check:
					updateOLED("NULL", "NULL", "Checking", "NULL");
					break;

				case charging:
					updateOLED("NULL", "NULL", HUMAN_CHARGING, String(batteryWatts())+"W");
					break;
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
void loop()
{
	//make sure mqtt is still connected
	if((!mqtt.connected()) || !mqtt.loop())
	{
		updateOLED("NULL", "Offline", "NULL", "NULL");
		mqttReconnect();
	}
	else
		updateOLED("NULL", "Online", "NULL", "NULL");

	//Send a heartbeat to keep the inverter awake
	heartbeat();

	//Check and display the runstate
	updateRunstate();

	//Transmit all data to MQTT
	sendData();

	//Set battery save state
	batterySave();

	delay(100);
}

//calcCRC and checkCRC are based on...
//https://github.com/angeloc/simplemodbusng/blob/master/SimpleModbusMaster/SimpleModbusMaster.cpp

void calcCRC(uint8_t frame[], byte frameSize) 
{
	unsigned int temp = 0xffff, flag;

	for(unsigned char i = 0; i < frameSize - 2; i++)
	{
		temp = temp ^ frame[i];

		for(unsigned char j = 1; j <= 8; j++)
		{
			flag = temp & 0x0001;
			temp >>= 1;

			if(flag)
				temp ^= 0xA001;
		}
	}

	// Bytes are reversed.
	frame[frameSize - 2] = temp & 0xff;
	frame[frameSize - 1] = temp >> 8;
}

bool checkCRC(uint8_t frame[], byte frameSize) 
{
	unsigned int calculated_crc, received_crc;

	received_crc = ((frame[frameSize-2] << 8) | frame[frameSize-1]);
	calcCRC(frame, frameSize);
	calculated_crc = ((frame[frameSize-2] << 8) | frame[frameSize-1]);
	return (received_crc = calculated_crc);
}

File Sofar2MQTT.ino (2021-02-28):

/*****
Sofar2mqtt is a remote control interface for Sofar solar and battery inverters.
It allows remote control of the inverter and reports the invertor status, power usage, battery state etc for integration with smart home systems such as Home Assistant and Node-Red vi MQTT.  
For read only mode, it will send status messages without the inverter needing to be in passive mode.  
It's designed to run on an ESP8266 microcontroller with a TTL to RS485 module such as MAX485 or MAX3485.  
Designed to work with TTL modules with or without the DR and RE flow control pins. If your TTL module does not have these pins then just ignore the wire from D5. 

Subscribe your MQTT client to:

sofar2mqtt/state

Which provides:

running_state  
grid_voltage  
grid_current  
grid_freq  
battery_power  
battery_voltage  
battery_current  
batterySOC  
battery_temp  
battery_cycles  
grid_power  
consumption  
solarPV  
today_generation  
today_exported  
today_purchase  
today_consumption  
inverter_temp  
inverterHS_temp  
solarPVAmps  

With the inverter in Passive Mode, send MQTT messages to:

sofar2mqtt/set/standby   - send value "true"  
sofar2mqtt/set/auto   - send value "true" or "battery_save"  
sofar2mqtt/set/charge   - send values in the range 0-3000 (watts)  
sofar2mqtt/set/discharge   - send values in the range 0-3000 (watts) 

battery_save is a hybrid auto mode that will charge from excess solar but not discharge.

(c)Colin McGerty 2021 colin@mcgerty.co.uk
calcCRC by angelo.compagnucci@gmail.com and jpmzometa@gmail.com
*****/
#include <Arduino.h>

//The divice name is used as the MQTT base topic. If you need more than one Sofar2mqtt on your network, give them unique names.
const char* deviceName = "sofar2mqtt";
const char* version = "v0.23";


// Wifi parameters. Fill in your wifi network name and password.
#include <ESP8266WiFi.h>
const char* wifiName = "xxxxx";
const char* wifiPassword = "xxxxx";
WiFiClient wifi;

// MQTT parameters
#include <PubSubClient.h>
const char* mqttClientID = deviceName;
const char* mqttServer = "mqtt";
const uint16_t mqttPort = 1883;
const char* mqttUsername = "auser";
const char* mqttPassword = "apassword";
PubSubClient mqtt(wifi);

// SoftwareSerial is used to create a second serial port, which will be deidcated to RS485.
// The built-in serial port remains available for flashing and debugging.
#include <SoftwareSerial.h>
#define SERIAL_COMMUNICATION_CONTROL_PIN D5 // Transmission set pin
#define RS485_TX HIGH
#define RS485_RX LOW
#define RXPin        D6  // Serial Receive pin
#define TXPin        D7  // Serial Transmit pin
SoftwareSerial RS485Serial(RXPin, TXPin);

// Sofar run states
#define waiting 0
#define check 1
#define charging 2
#define checkDischarge 3
#define discharging 4
#define epsState 5
#define faultState 6
#define permanentFaultState 7
unsigned int INVERTER_RUNNINGSTATE;
// Battery Save mode is a hybrid mode where the battery will charge from excess solar but not discharge.
bool BATTERYSAVE = false;
// Sofar Modbus commands.
// The two CRC bytes at the end are padded with zeros to make the frames the correct size. They get replaced using calcCRC at send time.
uint8_t slaveId = 0x01;
uint8_t readSingleRegister = 0x03;
uint8_t passiveMode = 0x42;
uint8_t getRunningState[] = {slaveId, readSingleRegister, 0x02, 0x00, 0x00, 0x04, 0x00, 0x00};
uint8_t getGridVoltage[] = {slaveId, readSingleRegister, 0x02, 0x06, 0x00, 0x01, 0x00, 0x00};
uint8_t getGridCurrent[] = {slaveId, readSingleRegister, 0x02, 0x07, 0x00, 0x02, 0x00, 0x00};
uint8_t getGridFrequency[] = {slaveId, readSingleRegister, 0x02, 0x0C, 0x00, 0x01, 0x00, 0x00};
uint8_t getBatteryPower[] = {slaveId, readSingleRegister, 0x02, 0x0D, 0x00, 0x01, 0x00, 0x00};
uint8_t getBatteryVoltage[] = {slaveId, readSingleRegister, 0x02, 0x0E, 0x00, 0x02, 0x00, 0x00};
uint8_t getBatteryCurrent[] = {slaveId, readSingleRegister, 0x02, 0x0F, 0x00, 0x10, 0x00, 0x00};
uint8_t getBatterySOC[] = {slaveId, readSingleRegister, 0x02, 0x10, 0x00, 0x02, 0x00, 0x00};
uint8_t getBatteryTemperature[] = {slaveId, readSingleRegister, 0x02, 0x11, 0x00, 0x02, 0x00, 0x00};
uint8_t getBatteryCycles[] = {slaveId, readSingleRegister, 0x02, 0x2C, 0x00, 0x01, 0x00, 0x00};
uint8_t getGridPower[] = {slaveId, readSingleRegister, 0x02, 0x12, 0x00, 0x02, 0x00, 0x00};
uint8_t getLoadPower[] = {slaveId, readSingleRegister, 0x02, 0x13, 0x00, 0x02, 0x00, 0x00};
uint8_t getSolarPV[] = {slaveId, readSingleRegister, 0x02, 0x15, 0x00, 0x02, 0x00, 0x00};
uint8_t getSolarPVToday[] = {slaveId, readSingleRegister, 0x02, 0x18, 0x00, 0x02, 0x00, 0x00};
uint8_t getGridExportToday[] = {slaveId, readSingleRegister, 0x02, 0x19, 0x00, 0x02, 0x00, 0x00};
uint8_t getGridImportToday[] = {slaveId, readSingleRegister, 0x02, 0x1A, 0x00, 0x02, 0x00, 0x00};
uint8_t getLoadPowerToday[] = {slaveId, readSingleRegister, 0x02, 0x1B, 0x00, 0x02, 0x00, 0x00};
uint8_t getInternalTemp[] = {slaveId, readSingleRegister, 0x02, 0x38, 0x00, 0x02, 0x00, 0x00};
uint8_t getHeatSinkTemp[] = {slaveId, readSingleRegister, 0x02, 0x39, 0x00, 0x02, 0x00, 0x00};
uint8_t getSolarPVCurrent[] = {slaveId, readSingleRegister, 0x02, 0x36, 0x00, 0x02, 0x00, 0x00};
uint8_t setStandby[] = {slaveId, passiveMode, 0x01, 0x00, 0x55, 0x55, 0x00, 0x00};
uint8_t setAuto[] = {slaveId, passiveMode, 0x01, 0x03, 0x00, 0x00, 0x00, 0x00};
uint8_t sendHeartbeat[] = {slaveId, 0x49, 0x22, 0x01, 0x22, 0x02, 0x00, 0x00};
uint8_t setDischarge[] = {slaveId, passiveMode, 0x01, 0x01, 0x00, 0x00, 0x00, 0x00};
uint8_t setCharge[] = {slaveId, passiveMode, 0x01, 0x02, 0x00, 0x00, 0x00, 0x00};

// This is the return object for the sendModbus() function. Since we are a modbus master, we
// are primarily interested in the responces to our commands.
struct modbusResponce
{
	uint8_t errorLevel;
	uint8_t data[64];
	uint8_t dataSize;
	char* errorMessage;
};

// These timers are used in the main loop.
unsigned long time_1 = 0;
#define HEARTBEAT_INTERVAL 9000
unsigned long time_2 = 0;
#define RUNSTATE_INTERVAL 5000
unsigned long time_3 = 0;
#define SEND_INTERVAL 10000
unsigned long time_4 = 0;
#define BATTERYSAVE_INTERVAL 3000

// Wemos OLED Shield set up. 64x48, pins D1 and D2
#include <SPI.h>
#include <Wire.h>
#include <Adafruit_GFX.h>
#include <Adafruit_SSD1306.h>
#define OLED_RESET 0  // GPIO0
Adafruit_SSD1306 display(OLED_RESET);
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

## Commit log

2021-01-25 Improved Battery_Save mode
2021-02-08 Improved JSON
    Fixes "Failed to parse json" error.
    [Sofar2MQTT.ino]
2021-02-27 Update Sofar2MQTT.ino
    Allow for multiple inverters by using the device name as the mqtt base topic.
2021-04-13 1.0
    Slight tuning of battery save mode to avoid switching too often.
2022-04-24 Version 2.0b1
    Major rewrite for stability by Adam Hill
    [Sofar2mqtt.ino]
2022-05-25 Update README.md
    MQTT topics are case sensitive, and Sofar2mqtt/state seems to be the correct topic
2022-11-07 Added systemIO_power register
    systemIO_power is the AC side of the inverter. Values in this register (0x0214) will match the power To/From the battery shown on the front LCD panel and in the Solarman app. Note the battery_power r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
2022-11-19 Fixed battery save mode
    [Sofar2mqtt.ino]
2022-11-21 Update configuration.yaml
    Switching the direction of in/out for systemIO_power to match battery_power
2022-11-26 Improve battery_save mode.
    With thanks to @Ernest-burgess
